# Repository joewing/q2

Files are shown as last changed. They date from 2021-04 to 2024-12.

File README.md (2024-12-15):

# Q2

A home-brew 12-bit mini-computer.

```
         __       __        
        /\ \     /\ \       000 | LDA | Z | A = [X]        
       /  \ \   /  \ \      001 | NOR | Z | A = A NOR [X] 
      / /\ \ \ / /\ \ \     010 | ADD | C | A = A + [X] 
     / / /\ \ \\/_/\ \ \    011 | SHR | C | A = [X] >> 1  
    / / /  \ \_\   / / /    100 | LEA | - | A = X 
   / / / __/ / /  / / /     101 | STA | - | [X] = A       
  / / / /\ \/ /  / / / __   110 | JMP | - | P = X
 / / /__\ \ \/  / / /_/\_\  111 | JFC | - | if !F: P = X  
/ / /____\ \ \ / /_____/ /   |
\/________\_\/ \________/   OOO D Z XXXXXXX - Operand
 joewing.net                     \ \_________ Zero Page
                                  \__________ Dereference
```

There are currently two hardware implementations of the Q2 instruction set:

  - [Q2](hardware/q2) - The bit-serial single-board discrete transistor implementation.
  - [Q2A](hardware/q2a) - A faster, parallel implementation using ATF16V8 PLDs.

Compared to the DEC PDP-8, the original Q2 would be like the PDP-8/S and
the Q2A would be like the PDP-8/I.

This repo contains the following subdirectories:
  - hardware - Hardware realizations.
    - [q2](hardware/q2) - The original discrete transistor Q2.
      - hdl - A Verilog model and test bench for simulating Q2 programs.
      - scad - An OpenSCAD 3d model for the case.
      - pcb - Schematics and PCB in KiCad
    - [q2a](hardware/q2a) - Programmable logic device implementation
      - pld - PLD files for programming the ATF16V8s and Verilog test bench
      - scad - An OpenSCAD 3d model for the case.
      - pcb - Schematics and PCB in KiCad
  - [q2asm](q2asm) - A Q2 assembler (in Rust).
  - [q2lc](q2lc) - A compiler for a simple language (in Rust).
  - [q2prog](q2prog) - A Q2 programmer (in Rust) for a Raspberry Pi
    (this is for the Q2 only; the Q2A requires an EEPROM programmer).
  - examples - Q2 example programs (assembly and Q2L).

See [joewing.net/projects/q2](https://joewing.net/projects/q2) for
more information.

## q2lc

q2lc is a compiler for Q2 programs. It is built using 'cargo build'
in the q2lc directory.

The Makefile will take care of compiling and assembling Q2L
programs in the examples directory automatically:

```
make examples/sieve.lst
```

This will compile sieve.q2l into sieve.q2 and then assemble
sieve.q2 using q2asm to generate sieve.lst along with sieve.q2p.

## q2asm

q2asm is the assembler for Q2 programs. It is built using 'cargo build'
in the q2asm directory.

The Makefile will take care of assembling programs in the examples
directory automatically:

```
make examples/hello.lst
```

This will generate the listing file for examples/hello.q2 as
examples/hello.lst.

## Instruction Set

All instructions are 1 word with the following format:

```
  FFF D Z XXXXXXX
   \  \ \    \____ Operand
    \  \ \________ Zero-Page    
     \  \_________ Dereference 
      \___________ Opcode
```

Instruction summary:

  Opcode  | Name  | F | Description
  ------- | ----- | - | ----------------
  000     | LDA   | Z | A = [X]
  001     | NOR   | Z | A = A NOR [X]
  010     | ADD   | C | A = A + [X]
  011     | SHR   | C | A = [X] >> 1
  100     | LEA   | - | A = X
  101     | STA   | - | [X] = A
  110     | JMP   | - | P = X
  111     | JFC   | - | if !F, P = X

The flag is set if carry ('C'), zero ('Z'), or left unchanged ('-').

The following address modes are supported:

  Value | DZ | Meaning
  ----- | --- | --------------------------------
  x     | 00 | current-page relative
  @x    | 10 | indirect through current page
  =x    | 01 | zero-page relative
  @=x   | 11 | indirect through zero page

For convenience, the assembler also supports two additional
address modes:

  Value | DZ | Meaning
  ----- | --- | --------------------------------
  #x    | 00 | immediate
  #@x   | 10 | immediate indirect

These cause an extra word to be allocated at the end of the
current page for an immediate value.

## Examples

```
; Negate: A = -A
  nor   #0
  add   #1
```

```
; Subtract: A - v
  nor   #0
  add   v       ; A = v - A - 1
  nor   #0      ; A = A - v
```

```
; Decrement A
  add   #-1
```

```
; NOT: A = ~A
  nor   #0
```

```
; OR: A = A | v
  nor   v
  nor   #0
```

```
; AND: A = A & v
  nor   #0
  sta   =t0   ; t0 = ~A
  lda   v
  nor   #0    ; A = ~v
  nor   =t0   ; A = ~(~A | ~v) = A & v
```

```
; Jump if F set
  jfc   $+2
  jmp   label
```

```
; Jump if a >= b
  lda   a
  nor   #0
  add   b
  jfc   ge
```

```
; Jump if a != b
  lda   a
  nor   #0
  add   b
  nor   #0
  jfc   ne
```

```
; Function call:
  lea   $+2   ; A = return address
  jmp   func

;...
func:
  sta   =ra   ; Save return address
  ; ...
  jmp   @=ra  ; Return

```

```
; Long jump
  jmp   @#addr
```

```
; Long call
  lea   $+2
  jmp   @#addr
```

```
; Rotate right function
; x0 >>> 1
ror:
  sta   =ra       ; save return address
  shr   =x0       ; A = x0 >> 1
  jfc   @=ra      ; return if no carry
  add   0x800
  jmp   @=ra
```

```
; Push A on to the stack
  sta   @=sp
  lda   =sp
  add   #-1
  sta   =sp
```

```
; Pop A off the stack
  lea   =1
  add   =sp
  sta   =sp
  lda   @=sp
```

## I/O

I/O is handled through address 0xFFF.

### LCD

Writes are directed to the LCD when the top 3 bits written to 0xFFF
are zero.  Writes to the LCD can be either commands or data.
The low 8-bits are sent directly to the LCD and the 9th bit determines
if data (0) or a command (1) is to be sent. Reads are not supported.

### Buttons

There are 5 buttons. Reading from 0xFFF returns the state of the
buttons in the low five bits where 0 is returned if the button is
pressed and 1 is returned if the button is not pressed.

### I2C

The SCL and SDA bits can be set by writing to 0xFFF with the top
bit set. Bit 9 controls SCL and bit 8 controls SDA.
Reads from 0xFFF return the state of the SCL and SDA bits.

### Memory Extension

The memory extension device allows the Q2 to address more than 4096
words of memory. This is accomplished through the use of two
additional latches: the data field (DF) and the instruction field (IF).
Memory accesses for indirect loads or stores have the data field
appended to the address. All other accesses have the instruction field
appended.

On reset, both the data and instruction fields are set to 0.
The data field can be set by writing 0xCxx to address 0xFFF (note that
the field is ignored for I/O). This will set the data field to xx.
The data field is copied to the instruction field when a jump takes
place.

### Summary

Writes:

  * 00 0 C DDDDDDDD - LCD
  * 10 C D 00000000 - I2C (C for SCL, D for SDA)
  * 11 0 0 0000000F - Field

Reads:

  * 11 C D 111KKKKK

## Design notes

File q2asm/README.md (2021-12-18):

# Q2 Assembler

q2asm is an assembler for Q2 programs.

See [joewing.net/projects/q2/asm](https://joewing.net/projects/q2/asm)
for more information.

## Building

* q2asm is written in Rust, so the first step is to
  [install Rust](https://www.rust-lang.org/tools/install)
  (note that rustup will also install cargo, which is required).
* Once rust and cargo are installed, run `cargo build`
  from this directory.
* q2asm will be available as `target/debug/q2asm`, which can
  be used from this location or copied to a location in your path.

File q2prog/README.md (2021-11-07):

# Q2 Programmer

q2prog is a Q2 programmer for the Raspberry Pi.

## Building

* q2prog is written in Rust, so the first step is to
  [install Rust](https://www.rust-lang.org/tools/install)
  (note that rustup will also install cargo, which is required).
* Once rust and cargo are installed, run `cargo build`
  from this directory.
* The q2prog will be available as `target/debug/q2prog`, which can
  be used from this location or copied to a location in your path.

## Usage

To program the Q2, connect a 40-pin connector to both the GPIO pins
of the Raspberry Pi and the Q2 (be sure the pins line up correctly).
Make sure all input switches on the Q2 are "off". Some of the data LEDs
will glow, but that is just due to pull-downs on some of the GPIO pins.

To write an assembled program (prog.q2p), on the Raspberry Pi run:

```
  q2prog write -f prog.q2p
```

For more options, see `q2prog -h`.

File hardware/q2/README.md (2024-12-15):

# Q2

Hardware for the Q2 12-bit bit-serial single-board discrete
transistor computer.

This is what it looks like:

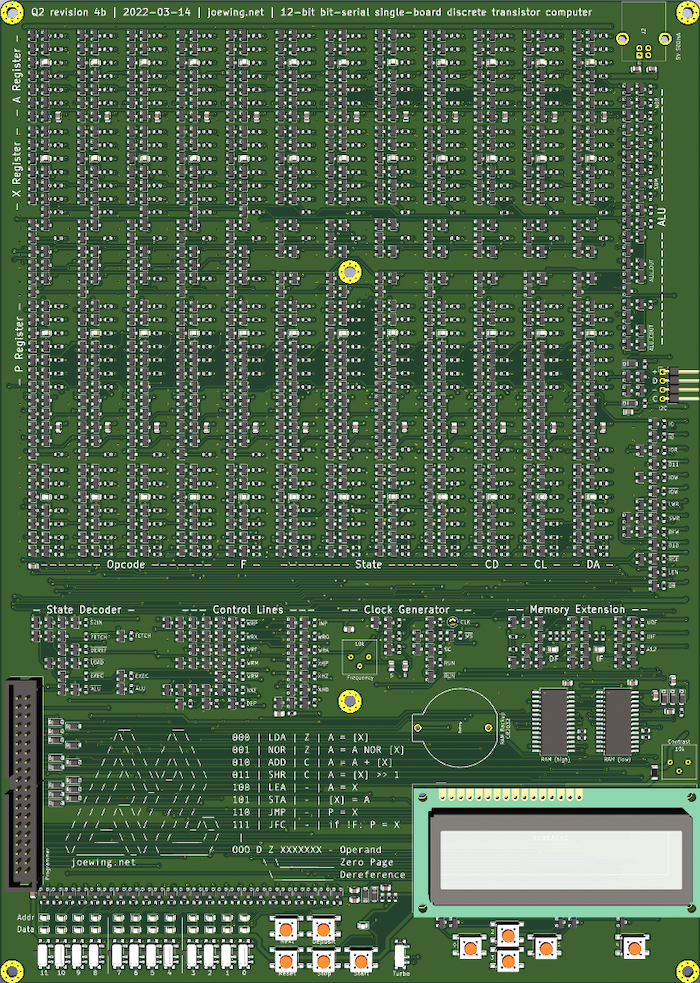
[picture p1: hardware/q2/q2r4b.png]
Q4 revision 4b


## PCB Fabrication and Assembly

The Q2 is a dual-layer PCB about the size of a sheet of paper allowing
it to be fabricated just about anywhere.
For assembly, the BOM is stored with the schematic to reference the
necessary surface-mount components. Due to the large number of components,
I use a turn-key assembly service. Although numerous, all of the components
are fairly standard making them cheap and widely available.

The large number of components makes the price for assembly
vary quite a bit from company to company. It's probably no surprise,
but the cheapest I've found is JLCPCB. I've been
satisfied with all the boards from them so far.

Unfortunately, JLCPCB's online Gerber viewer is incapable of showing a
board of this complexity.
To work around this without taking too big a leap of faith, I typically
upload several test boards to make sure I have component orientations
and positions correct.
Component orientation can be mostly fixed using
[JLCKicadTools](https://github.com/matthewlai/JLCKicadTools).
However, I typically run into a few components that need to be
fixed up when trying out new switches, etc.

Another issue with JLCPCB is that having more than 1000 of the same
component appears to cause problems such that they reject the BOM.
When necessary, I work around this by arbitrarily assigning different
values to the components to cause them to spill into multiple rows
in the BOM.

## Requirements

### For software development:

 * Rust - q2lc, q2asm, and q2prog are written in
  [Rust](https://www.rust-lang.org/tools/install).

### For programming:

 * Raspberry Pi - The GPIO pins on a
  [Raspberry Pi](https://www.raspberrypi.org) are used to
  program the Q2. The exact model does not matter, though older
  Pis with only 26 GPIO pins will not be able to read programs
  back from the Q2. A Raspberry Pi can be used as a complete
  development environment for the Q2.

### For simulation:

 * iverilog - [Icarus Verilog](http://iverilog.icarus.com) can be
  used to run the Verilog model.

### To make the hardware:

 * KiCad - The PCB and schematics are in
  [KiCad](https://kicad.org) 6. Note: the design was originally
  in KiCad 5 and the SOT-23 footprint became much larger with version 6.
  Therefore, to get the board to appear correctly it is necessary to use
  the footprint from KiCad 5. Unfortunately there doesn't seem to be
  a new footprint that works. See
  [Gitlab issue 2523](https://gitlab.com/kicad/libraries/kicad-footprints/-/issues/2523).
 * OpenSCAD - The 3D model for the case is written in
  [OpenSCAD](http://www.openscad.org).

## Programming

q2prog is run on a Raspberry Pi to program the Q2.
It is built using 'cargo build' in the q2prog directory.

To program the Q2, connect a 40-pin connector to both the GPIO pins
of the Raspberry Pi and the Q2 (be sure the pins line up correctly).
Make sure all input switches on the Q2 are "off". Some of the data LEDs
will glow, but that is just due to pull-downs on some of the GPIO pins.

To write a program (examples/hello.q2p) to the Q2:

```
make prog-hello
```

This will also build examples/hello.q2p if necessary.

To verify that the program was correctly written:

```
make verify-hello
```

Note that if q2prog is killed, the Raspberry Pi will hold the switches
in some state that is likely not zero. This means you will either
need to disconnect the Raspberry Pi or run q2prog to completion before
using the Q2.

## Simulation

Simulation of Q2 programs can be performed using the Verilog model.
The model reads in "test.hex" and runs the simulation outputting
a simulated 16x2 LCD (characters only) every time it is updated.

For convenience, the Makefile will take care of setting everything up.
Simply place the program to be simulated in the examples directory
and run 'make sim-name'. This will assemble and simulate
'examples/name.q2' (first compiling 'examples/name.q2l' if required).

## Power Consumption

The primary source of power consumption in the Q2 comes from pull-up
networks. For simplicity, most of the pull-ups are simply resistors,
though some of them have an LED in series to show the state.
We can easily compute the worst-case power draw by assuming all
pull-up networks are grounded.
The power consumption varies depending on the value of the resistor
and the presence of the LED:

  * 75 LEDs (2V drop) with 1k resistors: 75 * (5 - 2) / 1000 = 225mA
  * 6    1k resistors:  30.0mA
  * 10 4.7k resistors:  10.6mA
  * 48 6.8k resistors:  35.3mA
  * 244 10k resistors: 122.0mA
  * 48  22k resistors:  10.9mA
  * 31 100k resistors:   1.5mA

In addition to the pull-up network, the Q2 has the following components
that draw power:

  * The SRAMs each use 10mA (20mA total).
  * The LCD is assumed to use around 20mA.

This gives us a total power consumption of about 475mA.

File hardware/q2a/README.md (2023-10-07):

# Q2A

Hardware for the Q2 12-bit computer made from programmable logic devices.
Compared to the original Q2, the Q2A should be easier to have fabricated
(it uses through-hole components making it easy to hand assemble). In
addition, the Q2A has a faster clock and a nicer enclosure.

Note that the current iteration of the Q2A does not support the memory
extension device or I2C.

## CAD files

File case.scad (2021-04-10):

board_width = 150;
board_depth = 180;
base_height = 10;
panel_width = board_width;
panel_height = 100;
panel_depth = 10;
tol = 2;
thickness = 1.6 + tol;
switch_radius = 3.1;
switch_spacing = 3.5;
screw_radius = 1.7;
screw_head_radius = 2.8;
screw_head_height = 3;
standoff_height = base_height - 1.6;
standoff_radius = screw_head_radius * 1.5;


// center to center of the standoffs should be 143mm.
screw_offset = 3.5;
standoff_positions = [
    [screw_offset, screw_offset],
    [board_width - screw_offset, screw_offset],
    [screw_offset, board_depth - screw_offset],
    [board_width - screw_offset, board_depth - screw_offset]
];

module meniscus(height, radius) {
    difference() {
        cube([radius, radius, height]);
        cylinder(height, radius + 0.2, radius + 0.2);
    }
}

module rounded_cube(x, y, z, r = 3) {
    difference() {
        cube([x, y, z]);
        translate([x - r, y - r]) meniscus(z, r);
        translate([r, y - r]) rotate([0, 0, 90]) meniscus(z, r);
        translate([r, r]) rotate([0, 0, 180]) meniscus(z, r);
        translate([x - r, r]) rotate([0, 0, 270]) meniscus(z, r);
    }
}

module switches(x, y, count, notch) {
    for (i = [0:count-1]) {
        bump = x + i > 4 ? (x + i > 8 ? 9 : 5) : 1;
        translate([
            bump + (x + i) * switch_radius * switch_spacing + tol + 0.5,
            y * switch_radius * switch_spacing + tol,
            panel_depth - thickness
        ]) {
            cylinder(thickness, switch_radius, switch_radius, $fn=32);
        }
    }
}

module label(x, y, text) {
    size = 3;
    bump = x > 4 ? (x > 8 ? 9 : 5) : 1;
    translate([
        bump + x * switch_radius * switch_spacing - switch_radius + tol,
        y * switch_radius * switch_spacing - switch_radius * 2.5 + tol,
        panel_depth - thickness / 2
    ]) {
        linear_extrude(thickness / 2) {
            text(text = text, font = "Copperplate:style=bold", size = size, spacing=1.1);
        }
    }
}

module standoff(x, y) {
    translate([x + thickness, y + thickness, thickness]) {
        cylinder(standoff_height, standoff_radius, standoff_radius, $fn=16);
    }
}

module standoff_hole(x, y) {
    translate([x + thickness, y + thickness, 0]) {
        cylinder(standoff_height + thickness + tol, screw_radius, screw_radius, $fn=16);
        cylinder(screw_head_height, screw_head_radius, screw_head_radius, $fn=16);
    }
}

module render_base() {
    difference() {
        rounded_cube(
            board_width + 2 * thickness,
            board_depth + 2 * thickness,
            base_height + thickness
        );
        translate([thickness - tol, thickness - tol, thickness]) {
            rounded_cube(board_width + tol * 2, board_depth + tol * 2, base_height);
        }
    }
    for (pos = standoff_positions) {
        standoff(pos[0], pos[1]);
    }
}

module render_panel() {
    difference() {
        rounded_cube(panel_width + 2 * thickness, panel_height + 2 * thickness, panel_depth);
        translate([thickness - tol, thickness - tol, -thickness]) {
            rounded_cube(panel_width + tol * 2, panel_height + tol * 2, panel_depth);
        }
        
        // Data LEDs
        switches(1, 8, 12, false);
        label(1, 8, "Address");
        
        // Address LEDs
        switches(1, 6, 12, false);
        label(1, 6, "Data");
        
        // Power switch and LED.
        switches(1, 4, 1, true);
        switches(2, 4, 1, false);
        label(1, 4, "Power");
        
        // Speed
        switches(4, 4, 1, false);
        label(4, 4, " 5k");
        
        // Run LED, start, stop
        switches(6, 4, 1, false);
        switches(7, 4, 2, true);
        label(7, 4, "RUN");
        label(8, 4, "HLT");
        
        // Rest, increment, deposit
        switches(10, 4, 3, true);
        label(10, 4, "SET");
        label(11, 4, "INC");
        label(12, 4, "DEP");
        
        // Input switches
        switches(1, 2, 12, true);
        label(1, 2, "Input");
    }
}

difference() {
    union() {
        render_base();
        translate([0, base_height / 2 - tol, 0]) {
            rotate([60, 0, 0]) {
                render_panel();
            }
        }
    }
    for (pos = standoff_positions) {
        standoff_hole(pos[0], pos[1]);
    }
}

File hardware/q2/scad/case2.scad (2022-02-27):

board_width = 198;
board_height = 278;
wall_width = 2;
board_overlap = 2.5;
tol = 0.2;
screw_radius = 1.7;
screw_head_radius = 2.8;
screw_head_height = 3;
screw_offset = 3.5;
standoff_height = 8;
standoff_radius = screw_head_radius * 1.25;

case_width = board_width + (wall_width + tol) * 2;
case_height = board_height + (wall_width + tol) * 2;
case_depth = 1.6 + standoff_height + wall_width + tol;
midpoint = 140;

standoff_positions = [
    [screw_offset, screw_offset],
    [board_width - screw_offset, screw_offset],
    [board_width / 2, 79.9],
    [board_width / 2, 201.2],
    [screw_offset, board_height - screw_offset],
    [board_width - screw_offset, board_height - screw_offset],
];

module meniscus(height, radius) {
    difference() {
        cube([radius + 0.1, radius + 0.1, height]);
        translate([-0.1, -0.1, -0.1]) {
            cylinder(height + 0.1, radius + 0.1, radius + 0.1, $fn=32);
        }
    }
}

module rounded_cube(x, y, z, r = 3) {
    difference() {
        cube([x, y, z]);
        translate([x - r, y - r]) meniscus(z, r);
        translate([r, y - r]) rotate([0, 0, 90]) meniscus(z, r);
        translate([r, r]) rotate([0, 0, 180]) meniscus(z, r);
        translate([x - r, r]) rotate([0, 0, 270]) meniscus(z, r);
    }
}

module screw_hole(x, y) {
    translate([x + wall_width, y + wall_width, -tol]) {
        cylinder(
            standoff_height + wall_width + tol * 2,
            screw_radius,
            screw_radius,
            $fn=32
        );
        cylinder(
            screw_head_height + tol * 2,
            screw_head_radius,
            screw_head_radius,
            $fn=32
        );
    }
}

module clip() {
    base_radius = 4;
    board_width = 1.6;
    hole_radius = 1.4;
    difference() {
        union() {
            cylinder(d=hole_radius * 2, h=board_width, $fn=64);
            translate([0, 0, board_width]) {
                intersection() {
                    union() {
                        translate([0, 0, 0.5]) {
                            cylinder(d1 = hole_radius * 2.5, d2 = hole_radius * 1.5, h = 2, $fn=64);
                        }
                        cylinder(d1 = hole_radius * 2, d2 = hole_radius * 2.5, h = 0.5, $fn=64);
                    }
                    cube([hole_radius * 2, base_radius * 2, base_radius * 2], center=true);
                }
            }
        }
        translate([0, 0, (board_width + 20) / 2])cube([20, 0.4, 20], center=true);
    }
}

module standoff(x, y) {
    translate([x + wall_width, y + wall_width, wall_width]) {
        cylinder(standoff_height, standoff_radius, standoff_radius, $fn=32);
    }
    translate([x + wall_width, y + wall_width, wall_width + standoff_height]) {
        clip();
    }
}


module full_case() {
    union() {
        difference() {
            rounded_cube(case_width, case_height, case_depth);
            translate([wall_width + board_overlap, wall_width + board_overlap, wall_width]) {
                rounded_cube(
                    case_width - board_overlap * 2 - wall_width * 2,
                    case_height - board_overlap * 2 - wall_width * 2 + tol,
                    standoff_height
                );
            }
            translate([
                wall_width - tol,
                wall_width - tol,
                standoff_height + wall_width
            ]) {
                rounded_cube(
                    board_width + tol,
                    board_height + tol,
                    case_depth - standoff_height
                );
            }
        }
        for (pos = standoff_positions) {
            standoff(pos[0], pos[1]);
        }
    }
}


module interlock() {
    translate([0, midpoint, case_depth / 2]) {
        rotate([0, 90, 0]) {
            rotate([0, 0, -30]) {
                cylinder(case_width, case_depth, case_depth, $fn=3);
            }
        }
    }
}

module front_half() {
    translate([0, -0, 0]) {
        intersection() {
            full_case();
            union() {
                cube([case_width, midpoint, case_depth * 2]);
                interlock();
            }
        }
    }
}

module back_half() {
    translate([0, 0, 0]) {
        intersection() {
            full_case();
            difference() {
                translate([0, midpoint, 0]) {
                    cube([case_width, case_height - midpoint, case_depth * 2]);
                }
                interlock();
            }
        }
    }
}

//front_half();
back_half();

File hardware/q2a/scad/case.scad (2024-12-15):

board_width = 196;
board_depth = 160;
base_height = 11.6;
panel_width = board_width;
panel_height = 100;
panel_depth = 10;
panel_angle = 60;
pcb_thickness = 1.6;
tol = 2;
thickness = 3.6;
switch_radius = 3.6;
led_radius = 1.7;
switch_spacing = 3.5;
screw_radius = 1.9;
screw_head_radius = 2.9;
screw_head_height = 3.1;
standoff_height = thickness + base_height - screw_head_height - pcb_thickness;
standoff_radius = 3.6;
board_offset = 40;
switch_offset = 10;
extra = 1.0;    // Extra cutout for PCB


standoff_positions = [
    [standoff_radius, standoff_radius],
    [board_width - standoff_radius, standoff_radius],
    [standoff_radius, board_depth - standoff_radius],
    [board_width - standoff_radius, board_depth - standoff_radius],
];

module meniscus(height, radius) {
    difference() {
        translate([0,0, -1]) cube([radius, radius, height + 2]);
        cylinder(height + 0.01, radius + 0.2, radius + 0.2);
    }
}

module rounded_cube(x, y, z, r = 3) {
    difference() {
        cube([x, y, z]);
        translate([x - r, y - r]) meniscus(z + 0.01, r + 0.01);
        translate([r, y - r]) rotate([0, 0, 90]) meniscus(z + 0.01, r + 0.01);
        translate([r, r]) rotate([0, 0, 180]) meniscus(z + 0.01, r + 0.01);
        translate([x - r, r]) rotate([0, 0, 270]) meniscus(z + 0.01, r + 0.01);
    }
}

// 1 on each side, and 1/2 for nibble spacing:
switch_spacingx = panel_width / (3 * 0.5 + 2 * 0.5 + 15);

// 4 lines with extra on the top and bottom divides the panel into 5:
switch_spacingy = panel_height / (1 + 4);

function bumps(x) = x > 3 ? (x > 7 ? (x > 11 ? 2 : 1.5) : 1.0) : 0.5;

module switches(x, y, count, is_switch = true) {
    radius = is_switch ? switch_radius : led_radius;
    for (i = [0:count-1]) {
        bump = bumps(x + i);
        translate([
            thickness + (x + i + bump - 0.5) * switch_spacingx,
            (y) * switch_spacingy + base_height + thickness,
            panel_depth - thickness - tol
        ]) {
            cylinder(panel_depth, radius, radius, $fn=32);
        }
    }
}

module label(x, y, text, size = 3.2) {
    bump = bumps(x);
    translate([
        (x + bump - 0.5) * switch_spacingx,
        (y) * switch_spacingy - 2.5 * switch_radius + base_height + thickness,
        panel_depth + thickness / 2 + 0.01
    ]) {
        linear_extrude(thickness / 2) {
            text(text = text, font = "Copperplate:style=bold", size = size, spacing=1.1);
        }
    }
}

module standoff(x, y) {
    translate([x, y, thickness - 0.01]) {
        cylinder(standoff_height, standoff_radius, standoff_radius, $fn=32);
    }
}

module standoff_hole(x, y, flip = false) {
    translate([x, y, -tol - thickness]) {
        cylinder(standoff_height + tol + thickness + pcb_thickness, screw_radius, screw_radius, $fn=32);
        translate([0, 0, flip ? standoff_height + thickness + tol - screw_head_height : 0]) {
            cylinder(screw_head_height + tol, screw_head_radius, screw_head_radius, $fn=32);
        }
    }
}

module render_base() {
    difference() {
        rounded_cube(
            board_width + 2 * thickness,
            board_depth + 2 * thickness + board_offset,
            base_height + thickness
        );
        translate([thickness - extra, thickness - extra, thickness + 0.01]) {
            rounded_cube(board_width + extra * 2, board_depth + board_offset + extra * 2, base_height);
        }
    }
    translate([thickness, thickness + board_offset, 0]) {
        for (pos = standoff_positions) {
            standoff(pos[0], pos[1]);
        }
    }
}

module render_panel() {
    difference() {
        union() {
            difference() {
                rounded_cube(panel_width + 2 * thickness, panel_height + 2 * thickness + base_height, panel_depth + thickness);
                translate([thickness - extra, thickness + base_height - extra, -thickness]) {
                    rounded_cube(panel_width + 2 * extra, panel_height + 2 * extra, panel_depth + thickness);
                }
            }
            translate([0, base_height, 0]) {
                cube([thickness + standoff_radius, panel_height + thickness + extra, panel_depth + thickness]);
            }
            translate([panel_width - standoff_radius + thickness, base_height, 0]) {
                cube([thickness + standoff_radius, panel_height + thickness + extra, panel_depth + thickness]);
            }
            translate([thickness, base_height + panel_height + thickness + 2 * extra, 0]) {
                difference() {
                    rotate([60, 0, 0]) {
                        cube([panel_width, panel_depth * 2, panel_depth * 2]);
                    }
                    translate([-1, -panel_depth * 2, panel_depth + thickness - extra]) {
                        cube([panel_width + 2, panel_depth * 4, panel_depth * 4]);
                    }
                    translate([-1, -extra, -panel_depth * 2]) {
                        cube([panel_width + 2, panel_depth * 2, panel_depth * 4]);
                    }
                }
            }
            translate([thickness, thickness, -thickness]) {
                standoff(standoff_radius, base_height + standoff_radius);
                standoff(panel_width - standoff_radius, base_height + standoff_radius);
                standoff(standoff_radius, base_height + panel_height - standoff_radius);
                standoff(panel_width - standoff_radius, base_height + panel_height - standoff_radius);
            }
        }
        
        translate([thickness, thickness, thickness]) {
            standoff_hole(standoff_radius, base_height + standoff_radius, true);
            standoff_hole(panel_width - standoff_radius, base_height + standoff_radius, true);
            standoff_hole(standoff_radius, base_height + panel_height - standoff_radius, true);
            standoff_hole(panel_width - standoff_radius, base_height + panel_height - standoff_radius, true);
        }
        
        // Field LEDs
        switches(1, 4, 3, false);
        label(1, 4, "Field");
        
        // Address LEDs
        switches(4, 4, 12, false);
        label(4, 4, "Address");
        
        // Data LEDs
        switches(4, 3, 12, false);
        label(4, 3, "Data");
        
        // Power switch and LED
        switches(1, 2, 1, false);
        switches(2, 2, 1, true);
        label(1, 2, "Power");

        // Run LED, start, stop
        switches(4, 2, 1, false);
        switches(5, 2, 2, true);
        label(4, 2, "RUN");
        label(6, 2, "HLT");
        
        // Reset / Increment / Deposit
        switches(11, 2, 1, true);
        switches(13, 2, 2, true);
        label(11, 2, "SET");
        label(13, 2, "INC");
        label(14, 2, "DEP");
        
        // Field switches
        switches(1, 1, 3, true);
        label(1, 1, "Field");
        
        // Data switches
        switches(4, 1, 12, true);
        label(4, 1, "Input");
        
        label(11, 0.25, "Q2A", 12);
    }
}

difference() {
    union() {
        render_base();
        translate([0, board_offset / 2, base_height]) {
            height = (panel_height + thickness + base_height / 2) * sin(panel_angle);
            width = (panel_height + thickness + base_height / 2) * cos(panel_angle) - 2;
            translate([0, -board_offset / 4, 0]) difference() {
                cube([board_width + thickness * 2, width, height]);
                translate([-1, -1, 0]) rotate([panel_angle, 0, 0]) {
                    cube([board_width + thickness * 2 + 2, board_depth, height]);
                }
                translate([thickness - extra, 0, -1]) {
                    cube([board_width + extra * 2, board_depth + extra + board_offset, height + 2]);
                }
            }
        }
        translate([0, base_height / 2 - 0.2, 2]) {
            rotate([panel_angle, 0, 0]) {
                render_panel();
            }
        }
    }
    translate([thickness, thickness + board_offset, thickness]) {
        for (pos = standoff_positions) {
            standoff_hole(pos[0], pos[1]);
        }
    }
}

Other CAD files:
hardware/q2a/scad/led-stand.scad

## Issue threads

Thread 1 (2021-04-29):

Support for some unix-like environment?

dumblob, 2021-04-29:
First of all, this looks awesome! It's great to someone nowadays to play with such stuff! It reminds me of https://monster6502.com/ .

A year ago I saw https://collapseos.org/ . Few weeks ago I saw https://github.com/EtchedPixels/FUZIX . Today I see *q2*.

Have you thought of some unix-like interactive environment for *q2* or something like the Collapse OS?

----

Btw. what were your thoughts of constructing own memory from "discrete" parts? I'm asking because that was the first thing I was looking for when I saw the description "12-bit single-board discrete transistor computer" :wink:.

joewing, 2021-04-30:
Yeah, the MOnSter 6502 is a cool project.
It would be neat to have a high-level language and small OS environment, but for now I'm more focused on the actual hardware aspects. I think having external storage in the form of EEPROM would be necessary to make something like an OS useful (which is why I'm looking into an I2C interface now).

As far as RAM is concerned, it's tricky because it would use so many transistors. Even just the address decoder would be a lot of transistors. Of course, creating the PCB would be fairly easy (just replicate the same thing 2048 times or whatever), but it would be huge (and/or many), expensive, and power-hungry. This is why old computers used core memory, Williams tubes, delay lines, etc. Also, having the RAM be non-volatile is a must I think, so that also limits power consumption or forces the use of something like core memory.

dumblob, 2021-04-30:
>which is why I'm looking into an I2C interface now

I2C sounds pretty complex for such a simple device - but probably worth it considering you want to connect modern chips to it :wink:.

Regarding RAM - I was first thinking of delay lines, but that wouldn't scale. Second thought was core memory which I thought would be possible to completely redesign for PCB manufacturing. And that's what I was first looking for in your schemes :wink:. And thanks for the pointer to Willliams tubes - they seem extremely power hungry and sensitive to the environment, but it's an interesting piece of technology. Not sure though whether the decoder could be slimmed down - will think about it a bit ;)

dumblob, 2021-11-20:
Btw. regarding delay line RAM there are some interesting attempts to make it work as a DIY product:

http://www.decodesystems.com/delay-line-memory.html
http://jhallenworld.blogspot.com/2014/01/acoustic-delay-line-memory.html
https://www.youtube.com/watch?v=tQyX3F4ggM8

To me it still looks a bit easier than to immitate core memory with SMD parts on a PCB (if even possible).

Also the only thing I know of which is "fast" (in terms of "useful for a CPU from discrete components") and non-volatile is bubble memory. But its consumption is also non-negligible (because its operating temperature is around 45 Celsius if I'm not mistaken which means also tens of seconds delay when "booting"). It's though IMHO rather impossible to construct bubble memory from discrete components as many parts of it aren't manufactured for any existing product. Twister memory (predecessor to bubble memory) could work, but it's essentially a smaller variant of core memory which again means it's rather impossible to manufacture.

Maybe we could think of some capacitor memory - two PCBs (with very fine cell-like etched structures) on top of each other with some thin insulator in between and refreshing oscillator. IDK, just crazy brainstorming ...

dumblob, 2022-05-04:
After discovering http://www.northdownfarm.co.uk/rory/tim/tim-8.htm I think [capacitor memory](https://hackaday.io/page/2506-diode-capacitor-ram ) (in an SMD miniaturized form perhaps on doublesided PCBs) is a viable option even for many kilobytes of memory.

Thoughts?

joewing, 2022-05-08:
I've put some thought into using a DRAM like structure using two NMOS transistors and a capacitor per bit. The implementation is pretty straightforward and it uses about as few components as I think one can get away with. The diode version might be somewhat cheaper to implement, though I haven't done much experimentation with it.

For a DRAM of say, 1024 words, which is probably about the minimum number that would be useful I think, it would take 2*12*1024 = 24576 transistors and 12288 capacitors just for the storage. Assuming we could somehow share the sense amplifiers, the extra transistors for that would be negligible (probably nor more than 10 or so transistors?). I would guess this would have to be divided among multiple (hopefully identical) PCBs, and each would end up with its own sense amplifier. Implementing an address decoder would take lg(1024) = 10 transistors per word or 10240 transistors assuming the obvious implementation, though that could be reduced to slightly more than 5120 by re-using the outputs of some transistors. So the whole thing would come to something like 30k transistors. Getting that many transistors on a single PCB probably isn't realistic, but 2k would probably be doable. So that comes to 16 PCBs each with around 2k transistors to handle 64 words (768 bits).

Of course, the more complicated part would be adding extra states to handle pre-charge for each memory access and a periodic refresh. For the refresh, each DRAM board could potentially be refreshed in parallel during ALU operations (assuming each board had its own sense amplifiers). This would require the addition of a 6-bit counter. Then again, if we add a sense amplifier for each 8 words, we could get away with just using the ALU state machine to drive the refresh.

In any case, it's a neat idea.. though I don't particularly like the idea of making the ram volatile.

dumblob, 2022-05-09:
>In any case, it's a neat idea.. though I don't particularly like the idea of making the ram volatile.

It is definitely risky. But really neat as you say. If I found some time in the coming years (yeah, family life is very unpredictable :wink:), I will think about building such memory with refresh.

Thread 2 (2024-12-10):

[Suggestion] Release with gerber files

bastetfurry, 2024-12-10:
Due to the complexity of the project it would be cool if, for people who just want the hardware to play around with, you could add ready to use gerber and BOM files one can upload to, for example, JLC.
Especially with the little "bug/feature" of KiCAD 6 with the larger mosfet part.

joewing, 2024-12-14:
I just attached the gerber files and BOM used to create the 4c version of the board to the release: https://github.com/joewing/q2/releases/tag/rev4b

That should include everything necessary to have the board produced and assembled by JLCPCB. It's been a while, but I think that board works pretty much as is as long as you don't push the clock frequency too much.
I've made some more recent changes, but I haven't actually pulled the trigger on producing the board yet.

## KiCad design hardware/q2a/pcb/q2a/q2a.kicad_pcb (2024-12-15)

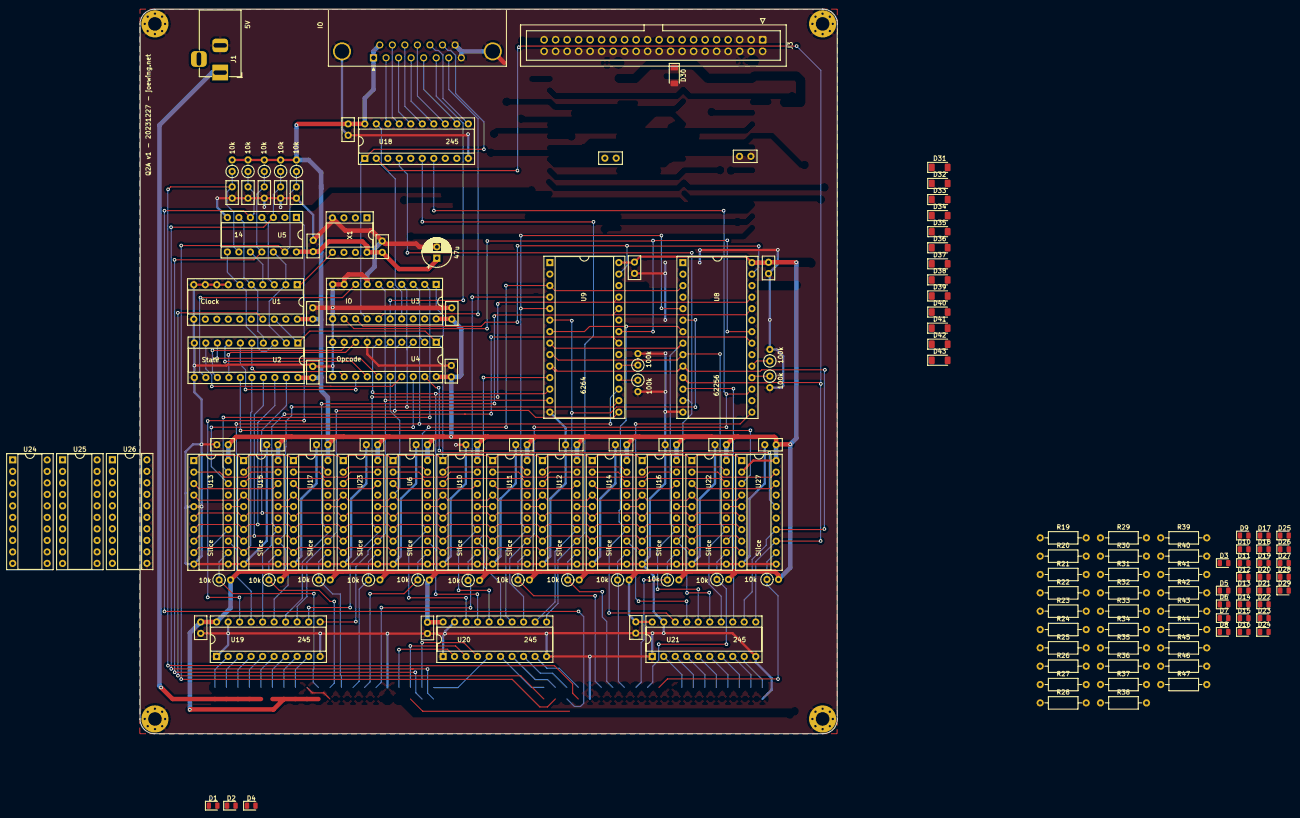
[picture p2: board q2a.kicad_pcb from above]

Board: 2 copper layers, 154.0 x 160.0 mm, 159 parts (0 on the bottom side), 191 nets.

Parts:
C1, C2, C3, C4, C5, C6, C7, C8, C10, C11, C12, C13, C14, C15, C16, C17, C18, C19, C20, C21, C22, C23, C24, C25, C26, C27, C28, C29, C30, C31, C32: 0.1u; C_Disc_D5.0mm_W2.5mm_P2.50mm
C9: 47u; CP_Radial_D6.3mm_P2.50mm
D1, D2, D3, D4, D5, D6, D7, D8, D9, D10, D11, D12, D13, D14, D15, D16, D17, D18, D19, D20, D21, D22, D23, D24, D25, D26, D27, D28, D29: LED; LED_0805_2012Metric
D30, D31, D32, D33, D34, D35, D36, D37, D38, D39, D40, D41, D42, D43: 1N4148; D_MiniMELF
H1, H2, H3, H4: MountingHole_Pad; MountingHole_3mm_Pad_Via
J1: Barrel_Jack_MountingPin; BarrelJack_Horizontal
J2: IO; DSUB-15_Female_Horizontal_P2.77x2.84mm_EdgePinOffset7.70mm_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
J3: Programmer; IDC-Header_2x20_P2.54mm_Vertical
R1, R2, R3, R4, R5, R6, R11, R12, R13, R14, R15, R16, R17, R18, R48, R49, R50: 10k; R_Axial_DIN0207_L6.3mm_D2.5mm_P2.54mm_Vertical
R7, R8, R9, R10: 100k; R_Axial_DIN0207_L6.3mm_D2.5mm_P2.54mm_Vertical
R19, R20, R21, R22, R23, R24, R25, R26, R27, R28, R29, R30, R31, R32, R33, R34, R35, R36, R37, R38, R39, R40, R41, R42, R43, R44, R45, R46, R47: 10k; R_Axial_DIN0207_L6.3mm_D2.5mm_P10.16mm_Horizontal
U1: Clock; DIP-20_W7.62mm_Socket
U2: State; DIP-20_W7.62mm_Socket
U3: IO; DIP-20_W7.62mm_Socket
U4: Opcode; DIP-20_W7.62mm_Socket
U5: 14; DIP-14_W7.62mm_Socket
U6, U10, U11, U12, U13, U14, U15, U16, U17, U22, U23, U27: Slice; DIP-20_W7.62mm_Socket
U8: 62256; DIP-28_W15.24mm_Socket
U9: 6264; DIP-28_W15.24mm_Socket
U18, U19, U20, U21: 245; DIP-20_W7.62mm_Socket
U24: Field 2; DIP-20_W7.62mm_Socket
U25: Field 1; DIP-20_W7.62mm_Socket
U26: Field 0; DIP-20_W7.62mm_Socket
X1: CXO; DIP-8_W7.62mm_Socket

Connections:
/Bit 0/COUT: U22.3 (I3), U27.18 (IO2)
/Bit 0/IOOUT: U22.2 (I2), U27.19 (IO1)
/Bit 0/NEXTX: U22.16 (IO4), U27.5 (I5)
/Bit 1/COUT: U16.3 (I3), U22.18 (IO2)
/Bit 1/IOOUT: U16.2 (I2), U22.19 (IO1)
/Bit 1/NEXTX: U16.16 (IO4), U22.5 (I5)
/Bit 2/COUT: U14.3 (I3), U16.18 (IO2)
/Bit 2/IOOUT: U14.2 (I2), U16.19 (IO1)
/Bit 2/NEXTX: U14.16 (IO4), U16.5 (I5)
/Bit 3/COUT: U12.3 (I3), U14.18 (IO2)
/Bit 3/IOOUT: U12.2 (I2), U14.19 (IO1)
/Bit 3/NEXTX: U12.16 (IO4), U14.5 (I5)
/Bit 4/COUT: U11.3 (I3), U12.18 (IO2)
/Bit 4/IOOUT: U11.2 (I2), U12.19 (IO1)
/Bit 4/NEXTX: U11.16 (IO4), U12.5 (I5)
/Bit 5/COUT: U10.3 (I3), U11.18 (IO2)
/Bit 5/IOOUT: U10.2 (I2), U11.19 (IO1)
/Bit 5/NEXTX: U10.16 (IO4), U11.5 (I5)
/Bit 6/COUT: U6.3 (I3), U10.18 (IO2)
/Bit 6/IOOUT: U6.2 (I2), U10.19 (IO1)
/Bit 6/NEXTX: U6.16 (IO4), U10.5 (I5)
/Bit 7/COUT: U6.18 (IO2), U23.3 (I3)
/Bit 7/IOOUT: U6.19 (IO1), U23.2 (I2)
/Bit 7/NEXTX: U6.5 (I5), U23.16 (IO4)
/Bit 8/COUT: U17.3 (I3), U23.18 (IO2)
/Bit 8/IOOUT: U17.2 (I2), U23.19 (IO1)
/Bit 8/NEXTX: U17.16 (IO4), U23.5 (I5)
/Bit 10/CIN: U15.3 (I3), U17.18 (IO2)
/Bit 10/COUT: U13.3 (I3), U15.18 (IO2)
/Bit 10/IOIN: U15.2 (I2), U17.19 (IO1)
/Bit 10/IOOUT: U13.2 (I2), U15.19 (IO1)
/Bit 10/NEXTX: U13.16 (IO4), U15.5 (I5)
/Bit 10/X: U15.16 (IO4), U17.5 (I5)
ABUS0: U8.10 (A0), U9.10 (A0), U21.12 (B6), U27.14 (IO6)
ABUS1: U8.9 (A1), U9.9 (A1), U21.14 (B4), U22.14 (IO6)
ABUS2: U8.8 (A2), U9.8 (A2), U16.14 (IO6), U21.16 (B2)
ABUS3: U8.7 (A3), U9.7 (A3), U14.14 (IO6), U21.18 (B0)
ABUS4: U8.6 (A4), U9.6 (A4), U12.14 (IO6), U20.12 (B6)
ABUS5: U8.5 (A5), U9.5 (A5), U11.14 (IO6), U20.14 (B4)
ABUS6: U8.4 (A6), U9.4 (A6), U10.14 (IO6), U20.16 (B2)
ABUS7: U6.14 (IO6), U8.3 (A7), U9.3 (A7), U20.18 (B0)
ABUS8: U8.25 (A8), U9.25 (A8), U19.12 (B6), U23.14 (IO6)
ABUS9: U8.24 (A9), U9.24 (A9), U17.14 (IO6), U19.14 (B4)
ABUS10: U8.21 (A10), U9.21 (A10), U15.14 (IO6), U19.16 (B2)
ABUS11: U8.23 (A11), U9.23 (A11), U13.14 (IO6), U19.18 (B0)
C0: U2.16 (IO4), U6.9 (I9), U10.9 (I9), U11.9 (I9), U12.9 (I9), U13.9 (I9), U14.9 (I9), U15.9 (I9), U16.9 (I9), U17.9 (I9), U22.9 (I9), U23.9 (I9), U24.7 (I7), U25.7 (I7), U26.7 (I7), U27.9 (I9)
C1: U2.17 (I03), U6.8 (I8), U10.8 (I8), U11.8 (I8), U12.8 (I8), U13.8 (I8), U14.8 (I8), U15.8 (I8), U16.8 (I8), U17.8 (I8), U22.8 (I8), U23.8 (I8), U24.6 (I6), U25.6 (I6), U26.6 (I6), U27.8 (I8)
C2: U2.18 (IO2), U6.7 (I7), U10.7 (I7), U11.7 (I7), U12.7 (I7), U13.7 (I7), U14.7 (I7), U15.7 (I7), U16.7 (I7), U17.7 (I7), U22.7 (I7), U23.7 (I7), U24.5 (I5), U25.5 (I5), U26.5 (I5), U27.7 (I7)
C3: U2.19 (IO1), U6.6 (I6), U10.6 (I6), U11.6 (I6), U12.6 (I6), U13.6 (I6), U14.6 (I6), U15.6 (I6), U16.6 (I6), U17.6 (I6), U22.6 (I6), U23.6 (I6), U24.4 (I4), U25.4 (I4), U26.4 (I4), U27.6 (I6)
CARRY: U4.18 (IO2), U13.18 (IO2)
CIN0: U2.15 (IO5), U27.3 (I3)
CLK: U1.18 (IO2), U2.1 (I1/CLK), U3.1 (I1/CLK), U4.1 (I1/CLK), U6.1 (I1/CLK), U10.1 (I1/CLK), U11.1 (I1/CLK), U12.1 (I1/CLK), U13.1 (I1/CLK), U14.1 (I1/CLK), U15.1 (I1/CLK), U16.1 (I1/CLK), U17.1 (I1/CLK), U22.1 (I1/CLK), U23.1 (I1/CLK), U24.1 (I1/CLK), U25.1 (I1/CLK), U26.1 (I1/CLK), U27.1 (I1/CLK)
DBUS0: U8.11 (Q0), U18.2 (A0), U21.11 (B7), U26.3 (I3), U27.13 (IO7)
DBUS1: U8.12 (Q1), U18.3 (A1), U21.13 (B5), U22.13 (IO7), U25.3 (I3)
DBUS2: U8.13 (Q2), U16.13 (IO7), U18.4 (A2), U21.15 (B3), U24.3 (I3)
DBUS3: U8.15 (Q3), U14.13 (IO7), U18.5 (A3), U21.17 (B1)
DBUS4: U8.16 (Q4), U12.13 (IO7), U18.6 (A4), U20.11 (B7)
DBUS5: U8.17 (Q5), U11.13 (IO7), U18.7 (A5), U20.13 (B5)
DBUS6: U9.11 (Q0), U10.13 (IO7), U18.8 (A6), U20.15 (B3)
DBUS7: U4.6 (I6), U6.13 (IO7), U9.12 (Q1), U18.9 (A7), U20.17 (B1)
DBUS8: U3.6 (I6), U4.5 (I5), U9.13 (Q2), U19.11 (B7), U23.13 (IO7)
DBUS9: U3.5 (I5), U4.4 (I4), U9.15 (Q3), U17.13 (IO7), U19.13 (B5)
DBUS10: U3.4 (I4), U4.3 (I3), U9.16 (Q4), U15.13 (IO7), U19.15 (B3)
DBUS11: U3.3 (I3), U4.2 (I2), U9.17 (Q5), U13.13 (IO7), U19.17 (B1)
DEP: U1.6 (I6), U2.3 (I3), U5.8
FIELD0: R22.1, U8.2 (A12), U9.2 (A12), U26.14 (IO6)
FIELD1: R20.1, U8.26 (A13), U9.26 (A13), U25.14 (IO6)
FIELD2: R19.1, U8.1 (A14), U9.1 (A14), U24.14 (IO6)
FLAG: U2.9 (I9), U4.17 (I03)
GND: C1.2, C2.2, C3.2, C4.2, C5.2, C6.2, C7.2, C8.2, C9.2, C10.2, C11.2, C12.2, C13.2, C14.2, C15.2, C16.2, C17.2, C18.2, C19.2, C20.2, C21.2, C22.2, C23.2, C24.2, C25.2, C26.2, C27.2, C28.2, C29.2, C30.2, C31.2, C32.2, D1.1 (K), D2.1 (K), D3.1 (K), D4.1 (K), D5.1 (K), D6.1 (K), D7.1 (K), D8.1 (K), D9.1 (K), D10.1 (K), D11.1 (K), D12.1 (K), D13.1 (K), D14.1 (K), D15.1 (K), D16.1 (K), D17.1 (K), D18.1 (K), D19.1 (K), D20.1 (K), D21.1 (K), D22.1 (K), D23.1 (K), D24.1 (K), D25.1 (K), D26.1 (K), D27.1 (K), D28.1 (K), D29.1 (K), H1.1, H2.1, H3.1, H4.1, J1.2, J2.0 (PAD), J2.8, J2.15, J3.6 (GND), J3.9 (GND), J3.14 (GND), J3.20 (GND), J3.25 (GND), J3.30 (GND), J3.34 (GND), J3.39 (GND), R7.2, R8.2, R9.2, R10.2, U1.7 (I7), U1.8 (I8), U1.9 (I9), U1.10 (GND), U1.11 (I10/~OE), U2.10 (GND), U2.11 (I10/~OE), U3.7 (I7), U3.9 (I9), U3.10 (GND), U3.11 (I10/~OE), U4.7 (I7), U4.10 (GND), U4.11 (I10/~OE), U5.1, U5.7 (GND), U6.10 (GND), U6.11 (I10/~OE), U8.14 (GND), U9.14 (GND), U10.10 (GND), U10.11 (I10/~OE), U11.10 (GND), U11.11 (I10/~OE), U12.10 (GND), U12.11 (I10/~OE), U13.5 (I5), U13.10 (GND), U13.11 (I10/~OE), U14.10 (GND), U14.11 (I10/~OE), U15.10 (GND), U15.11 (I10/~OE), U16.10 (GND), U16.11 (I10/~OE), U17.10 (GND), U17.11 (I10/~OE), U18.10 (GND), U19.1 (A->B), U19.10 (GND), U19.19 (CE), U20.1 (A->B), U20.10 (GND), U20.19 (CE), U21.1 (A->B), U21.10 (GND), U21.19 (CE), U22.10 (GND), U22.11 (I10/~OE), U23.10 (GND), U23.11 (I10/~OE), U24.10 (GND), U24.11 (I10/~OE), U25.10 (GND), U25.11 (I10/~OE), U26.10 (GND), U26.11 (I10/~OE), U27.10 (GND), U27.11 (I10/~OE), X1.4 (GND)
INCP: U1.5 (I5), U2.4 (I4), U5.6
IO: U3.2 (I2), U13.19 (IO1)
unnamed: D1.2 (A), R19.2
unnamed: D2.2 (A), R20.2
unnamed: D3.2 (A), R21.2
unnamed: D4.2 (A), R22.2
unnamed: D5.2 (A), R23.2
unnamed: D6.2 (A), R24.2
unnamed: D7.2 (A), R25.2
unnamed: D8.2 (A), R26.2
unnamed: D9.2 (A), R27.2
unnamed: D10.2 (A), R28.2
unnamed: D11.2 (A), R29.2
unnamed: D12.2 (A), R30.2
unnamed: D13.2 (A), R31.2
unnamed: D14.2 (A), R32.2
unnamed: D15.2 (A), R33.2
unnamed: D16.2 (A), R34.2
unnamed: D17.2 (A), R35.2
unnamed: D18.2 (A), R36.2
unnamed: D19.2 (A), R37.2
unnamed: D20.2 (A), R38.2
unnamed: D21.2 (A), R39.2
unnamed: D22.2 (A), R40.2
unnamed: D23.2 (A), R41.2
unnamed: D24.2 (A), R42.2
unnamed: D25.2 (A), R43.2
unnamed: D26.2 (A), R44.2
unnamed: D27.2 (A), R45.2
unnamed: D28.2 (A), R46.2
unnamed: D29.2 (A), R47.2
unnamed: D30.1 (K), J3.15 (GPIO22)
unnamed: D31.1 (K), J3.12 (GPIO18/PWM0)
unnamed: D32.1 (K), J3.16 (GPIO23)
unnamed: D33.1 (K), J3.11 (GPIO17)
unnamed: D34.1 (K), J3.18 (GPIO24)
unnamed: D35.1 (K), J3.10 (GPIO15/RXD)
unnamed: D36.1 (K), J3.22 (GPIO25)
unnamed: D37.1 (K), J3.8 (GPIO14/TXD)
unnamed: D38.1 (K), J3.7 (GCLK0/GPIO4)
unnamed: D39.1 (K), J3.23 (SCLK0/GPIO11)
unnamed: D40.1 (K), J3.26 (~CE1/GPIO7)
unnamed: D41.1 (K), J3.19 (MOSI0/GPIO10)
unnamed: D42.1 (K), J3.24 (~CE0/GPIO8)
unnamed: D43.1 (K), J3.21 (MISO0/GPIO9)
unnamed: J2.10, U18.17 (B1)
unnamed: J2.12, U18.13 (B5)
unnamed: J2.13, U18.11 (B7)
unnamed: J2.11 (P111), U18.15 (B3)
unnamed: U1.1 (I1/CLK), X1.5 (OUT)
unnamed: U8.20 (~CS), U9.20 (~CS)
unnamed: R7.1, U8.18 (Q6)
unnamed: R8.1, U8.19 (Q7)
unnamed: R9.1, U9.18 (Q6)
unnamed: R10.1, U9.19 (Q7)
unnamed: J2.2, U18.18 (B0)
unnamed: J2.3, U18.16 (B2)
unnamed: J2.4, U18.14 (B4)
unnamed: J2.5, U18.12 (B6)
unnamed: R23.1, U19.2 (A0)
unnamed: R24.1, U19.3 (A1)
unnamed: R25.1, U19.4 (A2)
unnamed: R26.1, U19.5 (A3)
unnamed: R27.1, U19.6 (A4)
unnamed: R28.1, U19.7 (A5)
unnamed: R29.1, U19.8 (A6)
unnamed: R30.1, U19.9 (A7)
unnamed: R31.1, U20.2 (A0)
unnamed: R32.1, U20.3 (A1)
unnamed: R34.1, U20.4 (A2)
unnamed: R35.1, U20.5 (A3)
unnamed: R36.1, U20.6 (A4)
unnamed: R37.1, U20.7 (A5)
unnamed: R38.1, U20.8 (A6)
unnamed: R39.1, U20.9 (A7)
unnamed: R40.1, U21.2 (A0)
unnamed: R41.1, U21.3 (A1)
unnamed: R42.1, U21.4 (A2)
unnamed: R43.1, U21.5 (A3)
unnamed: R44.1, U21.6 (A4)
unnamed: R45.1, U21.7 (A5)
unnamed: R46.1, U21.8 (A6)
unnamed: R47.1, U21.9 (A7)
OP0: U2.8 (I8), U4.15 (IO5), U24.9 (I9), U25.9 (I9), U26.9 (I9)
OP1: U2.7 (I7), U4.14 (IO6)
OP2: U2.6 (I6), U4.13 (IO7)
OP3: U2.5 (I5), U4.12 (IO8)
RST: U1.2 (I2), U2.2 (I2), U5.12
RUN: R33.1, U1.17 (I03)
S0: U2.13 (IO7), U4.9 (I9)
S1: U2.14 (IO6), U4.8 (I8), U24.8 (I8), U25.8 (I8), U26.8 (I8)
START: U1.4 (I4), U5.10
STOP: U1.3 (I3), U5.4
STORE: U2.12 (IO8), U3.8 (I8)
VCC: C4.1, C7.1, C8.1, C9.1, C10.1, C11.1, C12.1, C13.1, C14.1, C15.1, C16.1, C17.1, C18.1, C19.1, C20.1, C21.1, C22.1, C23.1, C24.1, C25.1, C26.1, C27.1, C28.1, C29.1, C30.1, C31.1, C32.1, J2.1, J2.9, R1.2, R2.2, R3.2, R4.2, R5.2, R6.2, R11.2, R12.2, R13.2, R14.2, R15.2, R16.2, R17.2, R18.2, R21.1, R48.2, R49.2, R50.2, U1.20 (VCC), U2.20 (VCC), U3.20 (VCC), U4.20 (VCC), U5.14 (VCC), U6.20 (VCC), U8.28 (VCC), U9.28 (VCC), U10.20 (VCC), U11.20 (VCC), U12.20 (VCC), U13.20 (VCC), U14.20 (VCC), U15.20 (VCC), U16.20 (VCC), U17.20 (VCC), U18.20 (VCC), U19.20 (VCC), U20.20 (VCC), U21.20 (VCC), U22.20 (VCC), U23.20 (VCC), U24.20 (VCC), U25.20 (VCC), U26.20 (VCC), U27.2 (I2), U27.20 (VCC), X1.8 (Vcc)
WRF: U3.19 (IO1), U24.2 (I2), U25.2 (I2), U26.2 (I2)
X0: U4.19 (IO1), U27.16 (IO4)
ZP: U4.16 (IO4), U6.4 (I4), U10.4 (I4), U11.4 (I4), U12.4 (I4), U13.4 (I4), U14.4 (I4), U15.4 (I4), U16.4 (I4), U17.4 (I4), U22.4 (I4), U23.4 (I4), U27.4 (I4)
~DEPSW: C3.1, D32.2 (A), R3.1, U5.9
~INCPSW: C5.1, R4.1, U5.5
~IOCMD: J2.6, U3.16 (IO4)
~IOEN0: U3.17 (I03), U18.19 (CE)
~IORD: J2.14, U3.14 (IO6), U18.1 (A->B)
~IOWR: J2.7, U3.15 (IO5)
~MEMOE: U3.12 (IO8), U8.22 (~OE), U9.22 (~OE)
~MEMWE: U3.13 (IO7), U8.27 (~WE), U9.27 (~WE)
~RSTSW: C1.1, D30.2 (A), R1.1, U5.13
~STARTSW: C6.1, R5.1, U5.11
~STOPSW: C2.1, R2.1, U5.3
~SW0: D34.2 (A), R50.1, U27.12 (IO8)
~SW1: D36.2 (A), R48.1, U22.12 (IO8)
~SW2: D38.2 (A), R17.1, U16.12 (IO8)
~SW3: D40.2 (A), R15.1, U14.12 (IO8)
~SW4: D42.2 (A), R13.1, U12.12 (IO8)
~SW5: D43.2 (A), R12.1, U11.12 (IO8)
~SW6: D41.2 (A), R11.1, U10.12 (IO8)
~SW7: D39.2 (A), R6.1, U6.12 (IO8)
~SW8: D37.2 (A), R49.1, U23.12 (IO8)
~SW9: D35.2 (A), R18.1, U17.12 (IO8)
~SW10: D33.2 (A), R16.1, U15.12 (IO8)
~SW11: D31.2 (A), R14.1, U13.12 (IO8)

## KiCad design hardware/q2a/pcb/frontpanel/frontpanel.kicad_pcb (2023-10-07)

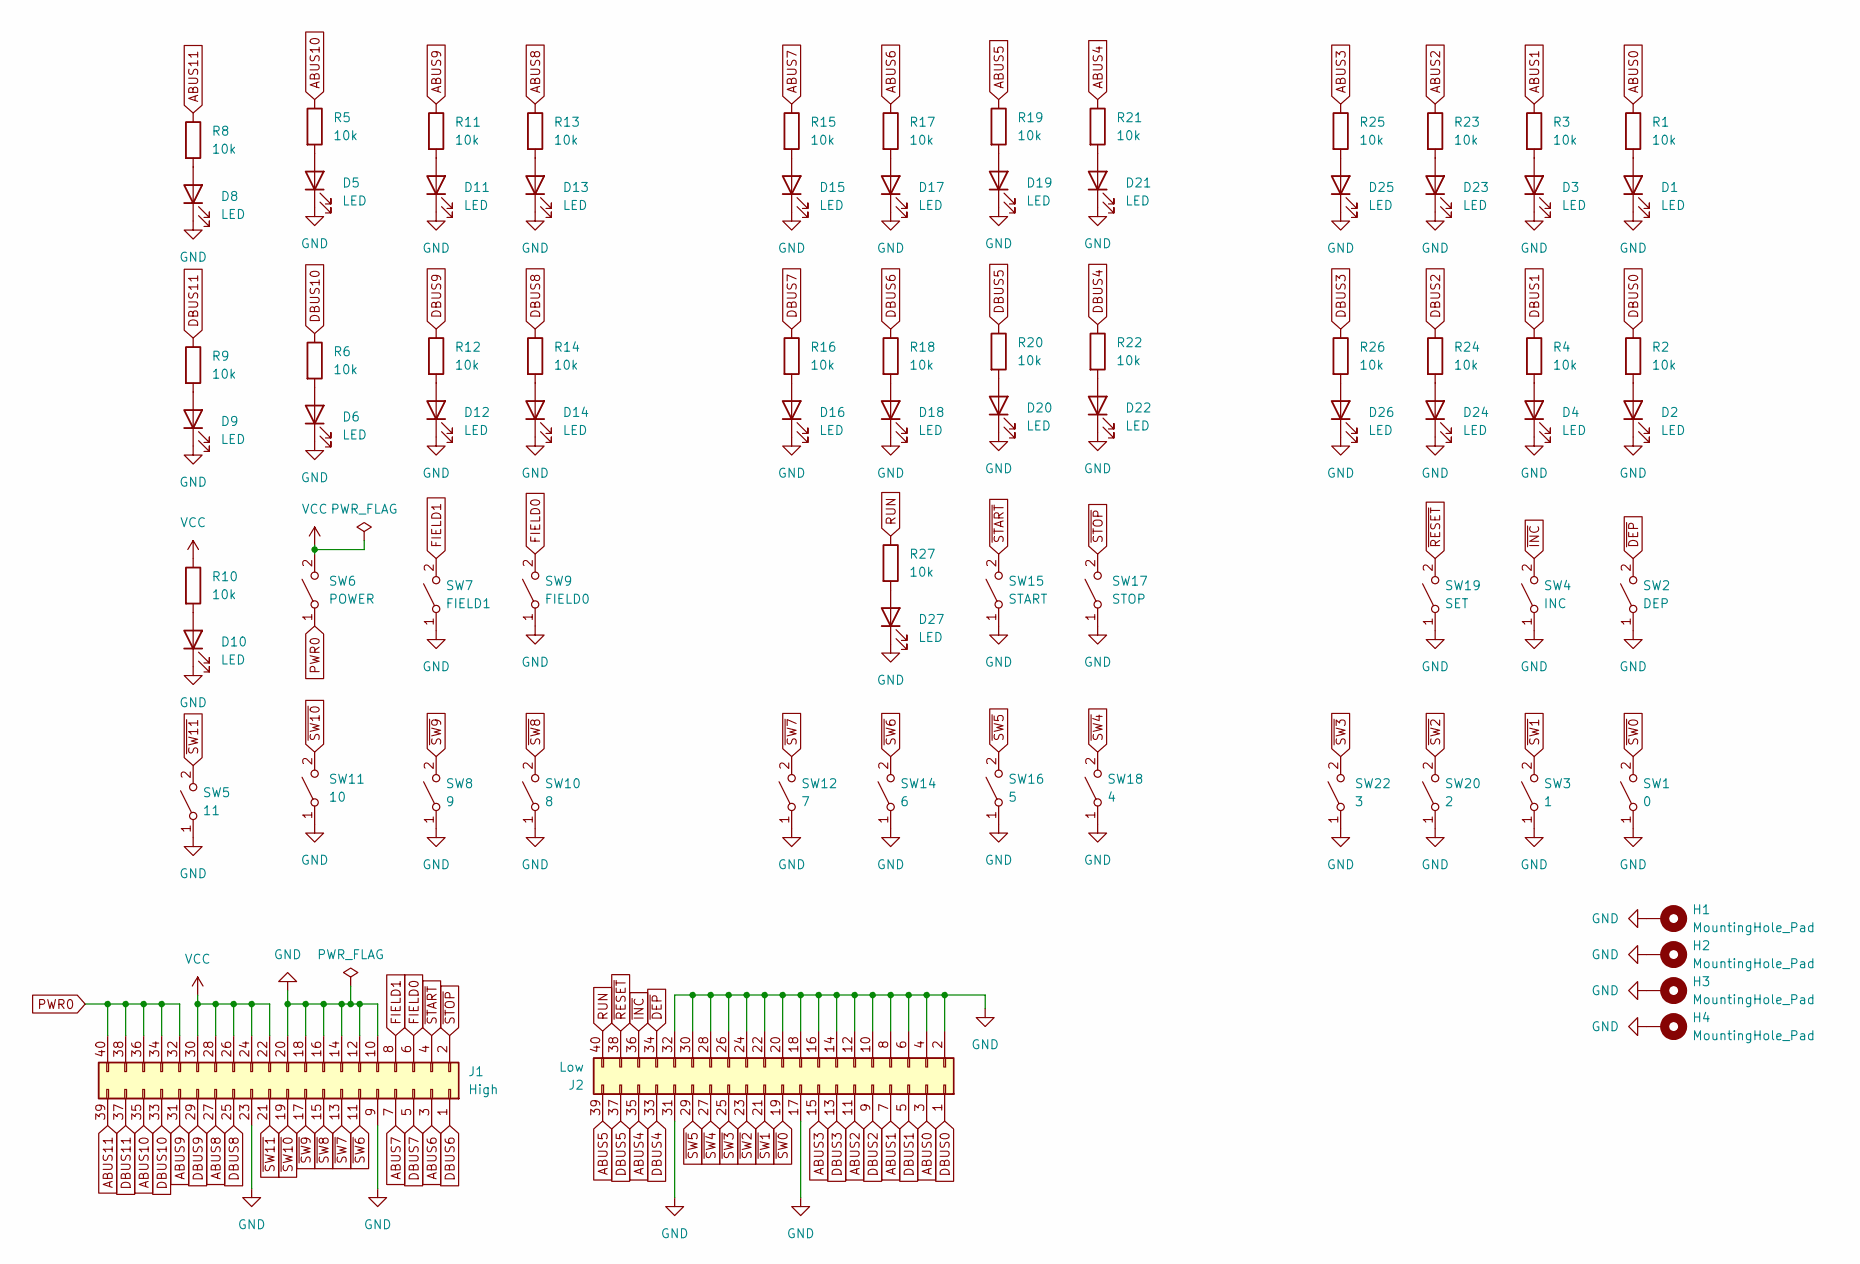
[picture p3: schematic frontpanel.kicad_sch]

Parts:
D1, D2, D3, D4, D5, D6, D8, D9, D10, D11, D12, D13, D14, D15, D16, D17, D18, D19, D20, D21, D22, D23, D24, D25, D26, D27: LED; LED_D3.0mm
H1, H2, H3, H4: MountingHole_Pad; MountingHole_3.2mm_M3_Pad_Via
J1: High; IDC-Header_2x20_P2.54mm_Vertical
J2: Low; IDC-Header_2x20_P2.54mm_Vertical
R1, R2, R3, R4, R5, R6, R8, R9, R10, R11, R12, R13, R14, R15, R16, R17, R18, R19, R20, R21, R22, R23, R24, R25, R26, R27: 10k; R_Axial_DIN0207_L6.3mm_D2.5mm_P10.16mm_Horizontal
SW1: 0; SW_MINI_TOGGLE
SW2: DEP; SW_MINI_TOGGLE
SW3: 1; SW_MINI_TOGGLE
SW4: INC; SW_MINI_TOGGLE
SW5: 11; SW_MINI_TOGGLE
SW6: POWER; SW_MINI_TOGGLE
SW7: FIELD1; SW_MINI_TOGGLE
SW8: 9; SW_MINI_TOGGLE
SW9: FIELD0; SW_MINI_TOGGLE
SW10: 8; SW_MINI_TOGGLE
SW11: 10; SW_MINI_TOGGLE
SW12: 7; SW_MINI_TOGGLE
SW14: 6; SW_MINI_TOGGLE
SW15: START; SW_MINI_TOGGLE
SW16: 5; SW_MINI_TOGGLE
SW17: STOP; SW_MINI_TOGGLE
SW18: 4; SW_MINI_TOGGLE
SW19: SET; SW_MINI_TOGGLE
SW20: 2; SW_MINI_TOGGLE
SW22: 3; SW_MINI_TOGGLE

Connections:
ABUS0: J2.3, R1.1
ABUS1: J2.7, R3.1
ABUS2: J2.11, R23.1
ABUS3: J2.15, R25.1
ABUS4: J2.35, R21.1
ABUS5: J2.39, R19.1
ABUS6: J1.3, R17.1
ABUS7: J1.7, R15.1
ABUS8: J1.27, R13.1
ABUS9: J1.31, R11.1
ABUS10: J1.35, R5.1
ABUS11: J1.39, R8.1
DBUS0: J2.1, R2.1
DBUS1: J2.5, R4.1
DBUS2: J2.9, R24.1
DBUS3: J2.13, R26.1
DBUS4: J2.33, R22.1
DBUS5: J2.37, R20.1
DBUS6: J1.1, R18.1
DBUS7: J1.5, R16.1
DBUS8: J1.25, R14.1
DBUS9: J1.29, R12.1
DBUS10: J1.33, R6.1
DBUS11: J1.37, R9.1
FIELD0: J1.6, SW9.2 (B)
FIELD1: J1.8, SW7.2 (B)
GND: D1.1 (K), D2.1 (K), D3.1 (K), D4.1 (K), D5.1 (K), D6.1 (K), D8.1 (K), D9.1 (K), D10.1 (K), D11.1 (K), D12.1 (K), D13.1 (K), D14.1 (K), D15.1 (K), D16.1 (K), D17.1 (K), D18.1 (K), D19.1 (K), D20.1 (K), D21.1 (K), D22.1 (K), D23.1 (K), D24.1 (K), D25.1 (K), D26.1 (K), D27.1 (K), H1.1, H2.1, H3.1, H4.1, J1.9, J1.10, J1.12, J1.14, J1.16, J1.18, J1.20, J1.23, J2.2, J2.4, J2.6, J2.8, J2.10, J2.12, J2.14, J2.16, J2.17, J2.18, J2.20, J2.22, J2.24, J2.26, J2.28, J2.30, J2.31, J2.32, SW1.1 (A), SW2.1 (A), SW3.1 (A), SW4.1 (A), SW5.1 (A), SW7.1 (A), SW8.1 (A), SW9.1 (A), SW10.1 (A), SW11.1 (A), SW12.1 (A), SW14.1 (A), SW15.1 (A), SW16.1 (A), SW17.1 (A), SW18.1 (A), SW19.1 (A), SW20.1 (A), SW22.1 (A)
unnamed: D1.2 (A), R1.2
unnamed: D2.2 (A), R2.2
unnamed: D3.2 (A), R3.2
unnamed: D4.2 (A), R4.2
unnamed: D5.2 (A), R5.2
unnamed: D6.2 (A), R6.2
unnamed: D8.2 (A), R8.2
unnamed: D9.2 (A), R9.2
unnamed: D10.2 (A), R10.2
unnamed: D11.2 (A), R11.2
unnamed: D12.2 (A), R12.2
unnamed: D13.2 (A), R13.2
unnamed: D14.2 (A), R14.2
unnamed: D15.2 (A), R15.2
unnamed: D16.2 (A), R16.2
unnamed: D17.2 (A), R17.2
unnamed: D18.2 (A), R18.2
unnamed: D19.2 (A), R19.2
unnamed: D20.2 (A), R20.2
unnamed: D21.2 (A), R21.2
unnamed: D22.2 (A), R22.2
unnamed: D23.2 (A), R23.2
unnamed: D24.2 (A), R24.2
unnamed: D25.2 (A), R25.2
unnamed: D26.2 (A), R26.2
unnamed: D27.2 (A), R27.2
PWR0: J1.32, J1.34, J1.36, J1.38, J1.40, SW6.1 (A)
RUN: J2.40, R27.1
VCC: J1.22, J1.24, J1.26, J1.28, J1.30, R10.1, SW6.2 (B)
~DEP: J2.34, SW2.2 (B)
~INC: J2.36, SW4.2 (B)
~RESET: J2.38, SW19.2 (B)
~START: J1.4, SW15.2 (B)
~STOP: J1.2, SW17.2 (B)
~SW0: J2.19, SW1.2 (B)
~SW1: J2.21, SW3.2 (B)
~SW2: J2.23, SW20.2 (B)
~SW3: J2.25, SW22.2 (B)
~SW4: J2.27, SW18.2 (B)
~SW5: J2.29, SW16.2 (B)
~SW6: J1.11, SW14.2 (B)
~SW7: J1.13, SW12.2 (B)
~SW8: J1.15, SW10.2 (B)
~SW9: J1.17, SW8.2 (B)
~SW10: J1.19, SW11.2 (B)
~SW11: J1.21, SW5.2 (B)

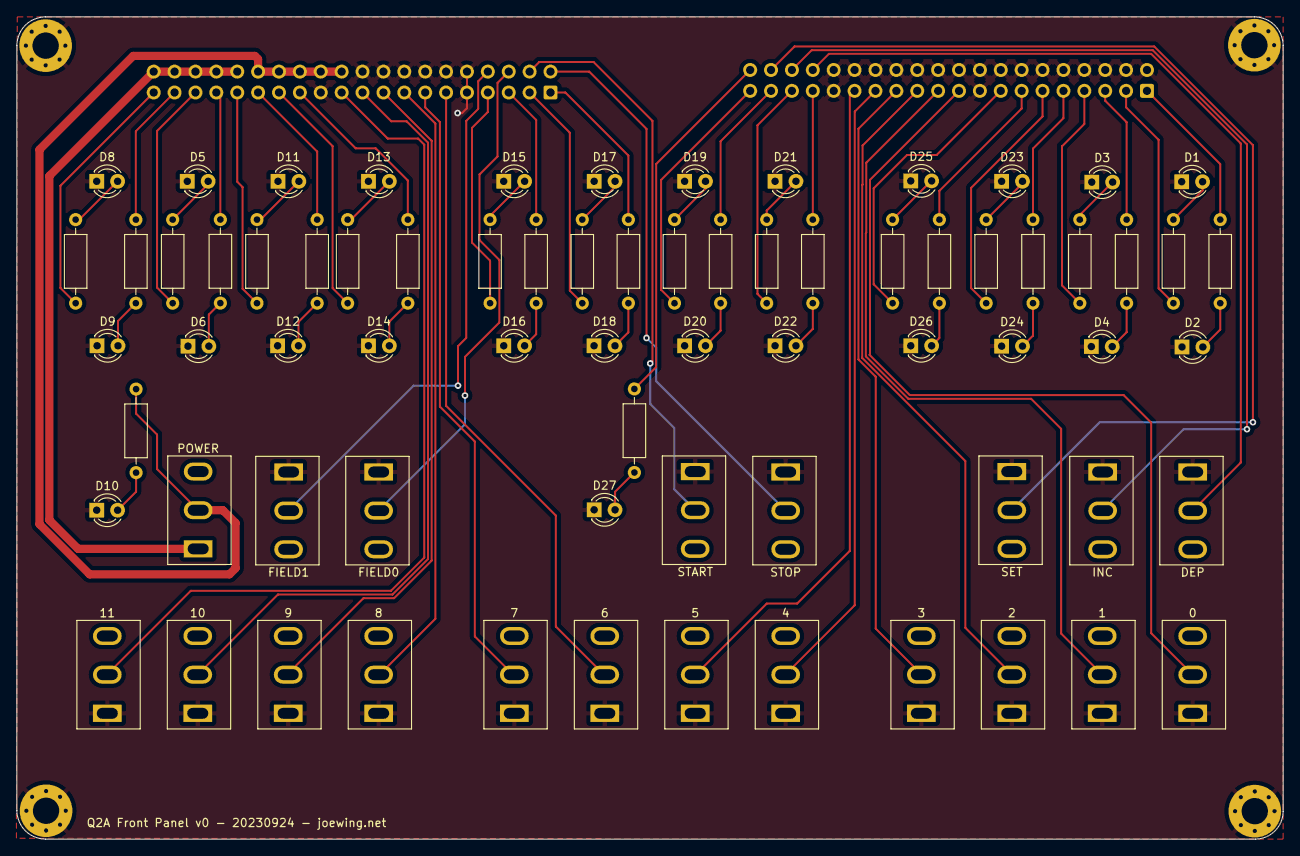
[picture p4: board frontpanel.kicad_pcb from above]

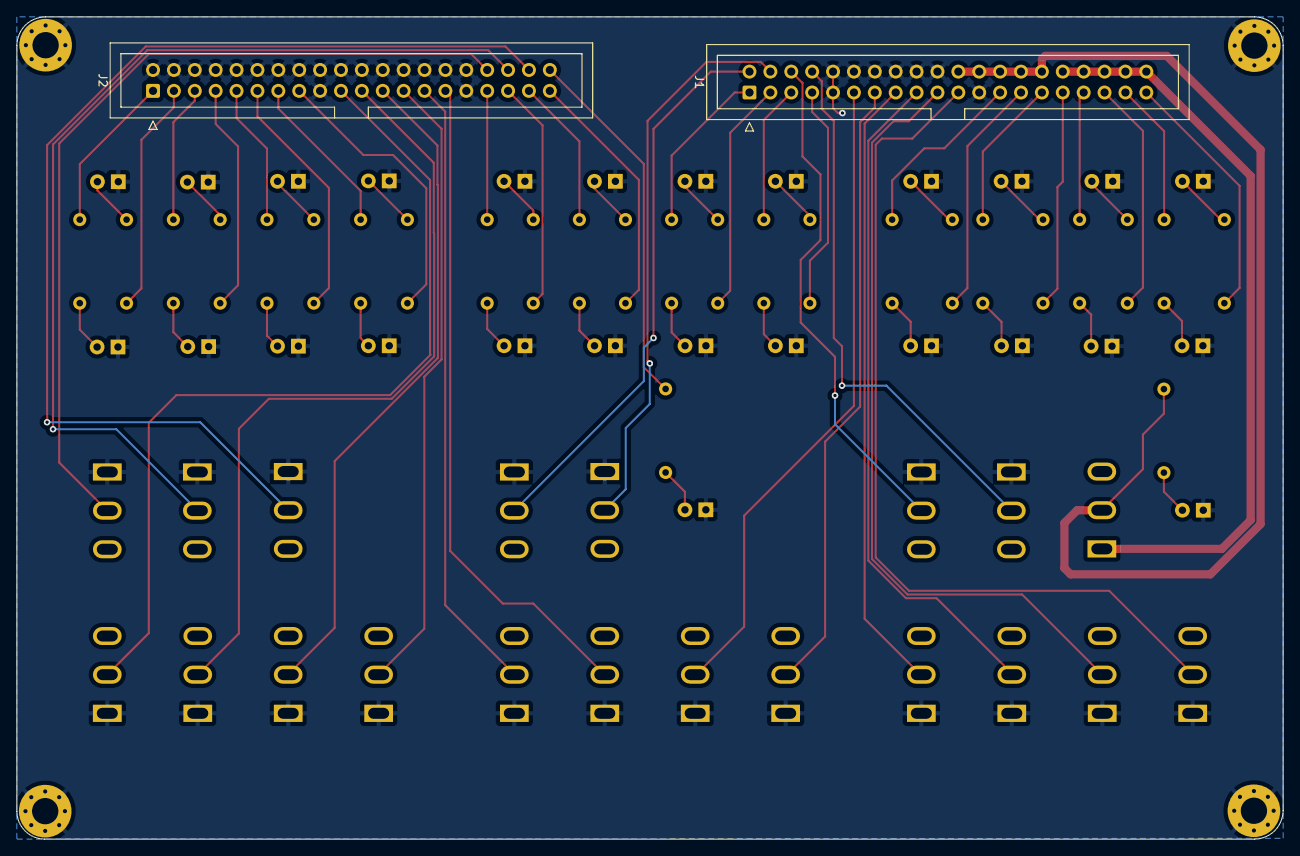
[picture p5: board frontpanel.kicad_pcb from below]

Board: 2 copper layers, 154.0 x 100.0 mm, 78 parts (2 on the bottom side), 73 nets.

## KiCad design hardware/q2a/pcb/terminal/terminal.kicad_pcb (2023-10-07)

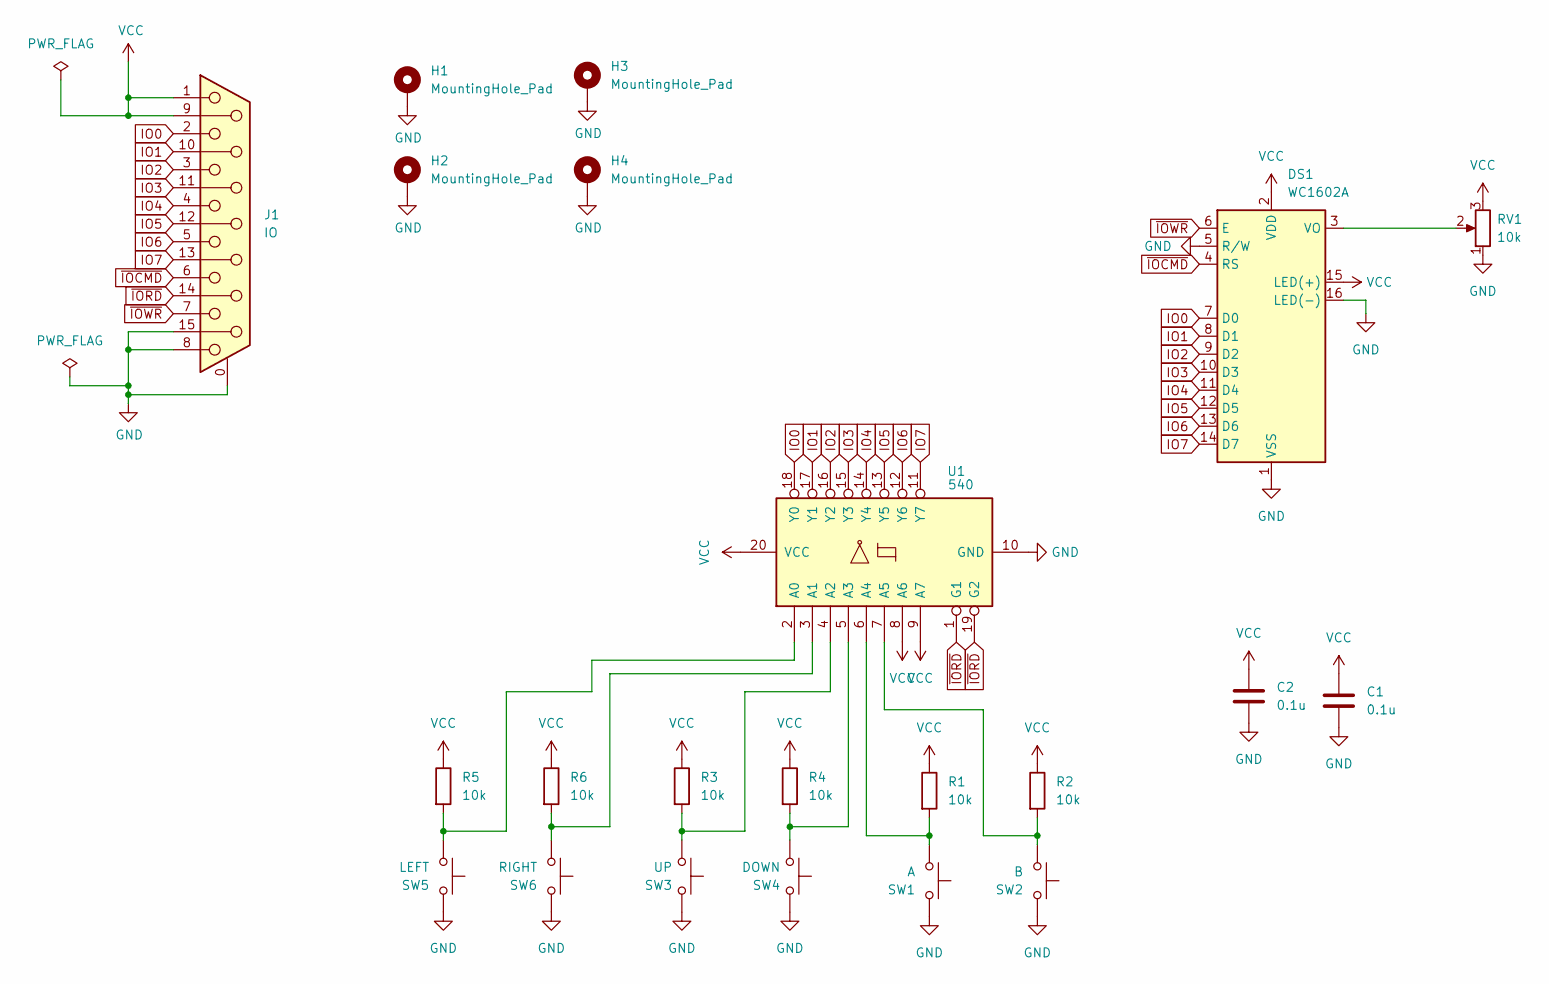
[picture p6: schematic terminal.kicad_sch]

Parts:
C1, C2: 0.1u; C_Disc_D3.4mm_W2.1mm_P2.50mm
DS1: WC1602A
H1, H2, H3, H4: MountingHole_Pad; MountingHole_3.2mm_M3_Pad_Via
J1: IO; DSUB-15_Female_Horizontal_P2.77x2.84mm_EdgePinOffset7.70mm_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
R1, R2, R3, R4, R5, R6: 10k; R_Axial_DIN0207_L6.3mm_D2.5mm_P10.16mm_Horizontal
RV1: 10k; Potentiometer_Bourns_3386P_Vertical
SW1: A; SW_PUSH_6mm
SW2: B; SW_PUSH_6mm
SW3: UP; SW_PUSH_6mm
SW4: DOWN; SW_PUSH_6mm
SW5: LEFT; SW_PUSH_6mm
SW6: RIGHT; SW_PUSH_6mm
U1: 540; DIP-20_W7.62mm_Socket

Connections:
GND: C1.2, C2.2, DS1.1 (VSS), DS1.5 (R/W), DS1.16 (LED(-)), H1.1, H2.1, H3.1, H4.1, J1.0 (PAD), J1.8, J1.15, RV1.1, SW1.2, SW2.2, SW3.2, SW4.2, SW5.2, SW6.2, U1.10 (GND)
IO0: DS1.7 (D0), J1.2, U1.18 (Y0)
IO1: DS1.8 (D1), J1.10, U1.17 (Y1)
IO2: DS1.9 (D2), J1.3, U1.16 (Y2)
IO3: DS1.10 (D3), J1.11 (P111), U1.15 (Y3)
IO4: DS1.11 (D4), J1.4, U1.14 (Y4)
IO5: DS1.12 (D5), J1.12, U1.13 (Y5)
IO6: DS1.13 (D6), J1.5, U1.12 (Y6)
IO7: DS1.14 (D7), J1.13, U1.11 (Y7)
unnamed: DS1.3 (VO), RV1.2
unnamed: R5.2, SW5.1, U1.2 (A0)
unnamed: R6.2, SW6.1, U1.3 (A1)
unnamed: R3.2, SW3.1, U1.4 (A2)
unnamed: R4.2, SW4.1, U1.5 (A3)
unnamed: R1.2, SW1.1, U1.6 (A4)
unnamed: R2.2, SW2.1, U1.7 (A5)
VCC: C1.1, C2.1, DS1.2 (VDD), DS1.15 (LED(+)), J1.1, J1.9, R1.1, R2.1, R3.1, R4.1, R5.1, R6.1, RV1.3, U1.8 (A6), U1.9 (A7), U1.20 (VCC)
~IOCMD: DS1.4 (RS), J1.6
~IORD: J1.14, U1.1 (G1), U1.19 (G2)
~IOWR: DS1.6 (E), J1.7

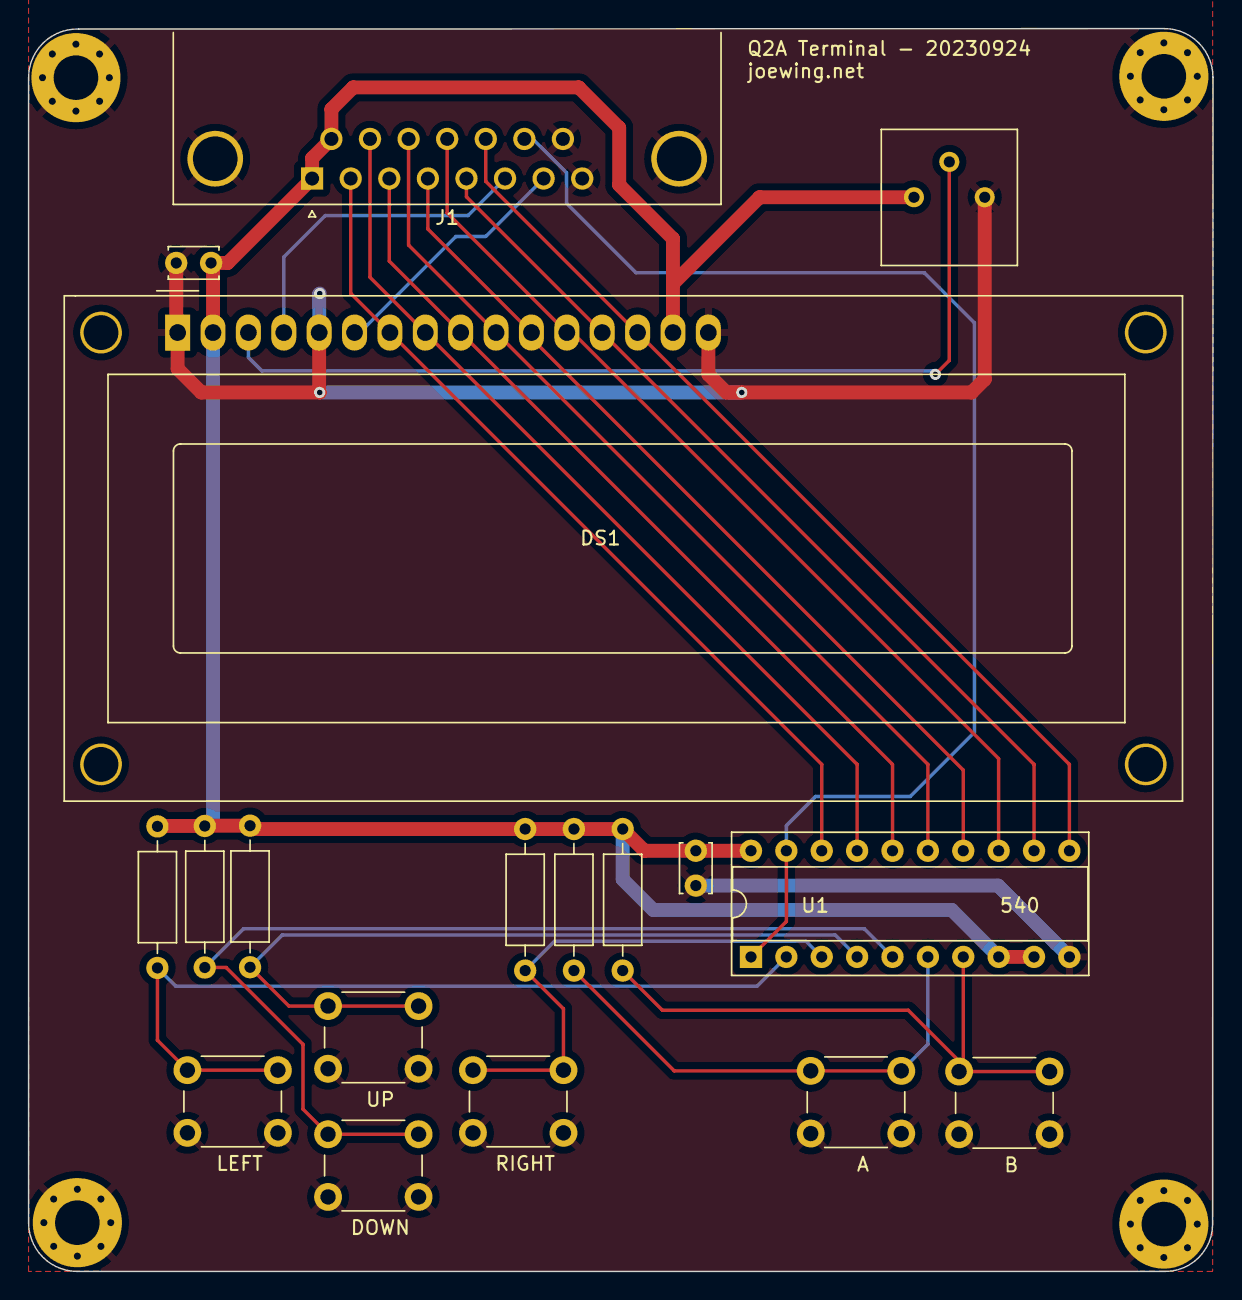
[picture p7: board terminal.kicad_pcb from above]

Board: 2 copper layers, 85.0 x 89.2 mm, 22 parts (0 on the bottom side), 20 nets.

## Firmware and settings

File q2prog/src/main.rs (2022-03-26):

use gpio_cdev::{Chip, LineRequestFlags, MultiLineHandle, LineHandle};
use gpio_cdev::Error;
use std::thread;
use std::time::Duration;
use std::u16;
use std::fs;
use clap::{App, crate_version, crate_authors, crate_name, Arg};
use std::num::ParseIntError;

const DEFAULT_DEVICE_PATH: &str = "/dev/gpiochip0";

// Least significant bits first.
const OUTPUT_PINS: [u32; 12] = [
    24, 25, 4, 7, 8, 9, 10, 11, 14, 15, 17, 18
];
const INPUT_PINS: [u32; 12] = [
    // Input available with 40-pin connector only.
    5, 6, 12, 13, 16, 19, 20, 21, 27, 2, 26, 3
];
const SET_PIN: u32 = 22;
const DEPOSIT_PIN: u32 = 23;

const DELAY_SHORT: Duration = Duration::from_millis(5);
const DELAY_LONG: Duration = Duration::from_millis(25);

pub struct ProgError {
    message: String
}

impl From<std::io::Error> for ProgError {
    fn from(e: std::io::Error) -> ProgError {
        ProgError {
            message: e.to_string()
        }
    }
}

impl From<Error> for ProgError {
    fn from(e: Error) -> ProgError {
        ProgError {
            message: e.to_string()
        }
    }
}

impl From<ParseIntError> for ProgError {
    fn from(e: ParseIntError) -> ProgError {
        ProgError {
            message: e.to_string()
        }
    }
}

pub struct FrontPanel {
    output_lines: MultiLineHandle,
    input_lines: Option<MultiLineHandle>,
    set_line: LineHandle,
    deposit_line: LineHandle
}

impl FrontPanel {
    fn press_button(&self, line: &LineHandle, dur: &Duration) -> Result<(), Error> {
        line.set_value(1)?;
        thread::sleep(DELAY_SHORT);
        line.set_value(0)?;
        thread::sleep(*dur);
        Ok(())
    }

    fn press_set(&self) -> Result<(), Error> {
        self.press_button(&self.set_line, &DELAY_LONG)
    }

    fn press_deposit(&self) -> Result<(), Error> {
        self.press_button(&self.deposit_line, &DELAY_SHORT)
    }

    fn set_value(&self, value: u16) -> Result<(), Error> {
        let mut temp = [0u8; 12];
        for i in 0..12 {
            if (value >> i) & 1 != 0 {
                temp[i] = 1u8;
            }
        }
        self.output_lines.set_values(&temp)
    }

    fn get_value(&self) -> Result<u16, Error> {
        let mut result = 0u16;
        let temp = self.input_lines.as_ref().unwrap().get_values()?;
        for i in 0..12 {
            if temp[i] != 0 {
                result |= 1 << i;
            }
        }
        Ok(result)
    }

    pub fn write_word(&self, addr: u16, word: u16) -> Result<(), Error> {
        eprintln!("write {:03x} = {:03x}", addr, word);
        self.set_value(addr)?;
        self.press_set()?;
        self.set_value(word)?;
        self.press_deposit()
    }

    pub fn read_word(&self, addr: u16) -> Result<u16, Error> {
        self.set_value(addr)?;
        self.press_set()?;
        let word = self.get_value()?;
        eprintln!("read {:03x} = {:03x}", addr, word);
        Ok(word)
    }

    pub fn cleanup(&self) -> Result<(), Error> {
        self.set_value(0u16)?;
        self.press_set()
    }
}

pub fn create_frontpanel(device_path: &str, read_enable: bool) -> Result<FrontPanel, Error> {
    let process_name = "q2prog";
    let mut chip = Chip::new(device_path)?;
    let output_lines = chip.get_lines(&OUTPUT_PINS)?.request(
        LineRequestFlags::OUTPUT | LineRequestFlags::OPEN_DRAIN | LineRequestFlags::ACTIVE_LOW,
        &[0u8; 12],
        process_name
    )?;
    let input_lines = if read_enable {
        Some(
            chip.get_lines(&INPUT_PINS)?.request(
                LineRequestFlags::INPUT | LineRequestFlags::ACTIVE_LOW,
                &[0u8; 12],
                process_name
            )?
        )
    } else {
        None
    };
    let set_line = chip.get_line(SET_PIN)?.request(
        LineRequestFlags::OUTPUT | LineRequestFlags::OPEN_DRAIN | LineRequestFlags::ACTIVE_LOW,
        0u8,
        process_name
    )?;
    let deposit_line = chip.get_line(DEPOSIT_PIN)?.request(
        LineRequestFlags::OUTPUT | LineRequestFlags::OPEN_DRAIN | LineRequestFlags::ACTIVE_LOW,
        0u8,
        process_name
    )?;
    Ok(FrontPanel{ output_lines, input_lines, set_line, deposit_line })
}

fn parse_word(word: &str) -> Result<u16, ProgError> {
    let result = u16::from_str_radix(word, 16)?;
    Ok(result)
}

fn do_write(device_path: &str, filename: &str) -> Result<usize, ProgError> {
    let data = fs::read_to_string(filename)?;
    let panel = create_frontpanel(device_path, false)?;
    let mut count = 0;
    for line in data.split('\n') {
        let parts: Vec<&str> = line.split(':').collect();
        if parts.len() == 2 {
            let addr = parse_word(parts[0])?;
            let word = parse_word(parts[1])?;
            panel.write_word(addr, word)?;
            count += 1;
        } else if line.len() > 0 {
            return Err(ProgError { message: format!("ERROR: invalid line: {}", line) })
        }
    }
    panel.cleanup()?;
    Ok(count)
}

fn do_verify(device_path: &str, filename: &str) -> Result<usize, ProgError> {
    let data = fs::read_to_string(filename)?;
    let panel = create_frontpanel(device_path, true)?;
    let mut count = 0;
    for line in data.split('\n') {
        let parts: Vec<&str> = line.split(':').collect();
        if parts.len() == 2 {
            let addr = parse_word(parts[0])?;
            let word = parse_word(parts[1])?;
            let actual = panel.read_word(addr)?;
            if word != actual {
                panel.cleanup()?;
                return Err(ProgError { message: format!("ERROR: verification failed at {:03X}: expected {:03X}, got {:03X}", addr, word, actual) })
            };
            count += 1;
        } else if line.len() > 0 {
            return Err(ProgError { message: format!("ERROR: invalid line: {}", line) })
        }
    }
    panel.cleanup()?;
    Ok(count)
}

fn do_reset(device_path: &str) -> Result<(), ProgError> {
    let panel = create_frontpanel(device_path, false)?;
    panel.cleanup()?;
    Ok(())
}

fn do_read(device_path: &str, filename: &str, start: u16, end: u16) -> Result<usize, ProgError> {
    let panel = create_frontpanel(device_path, true)?;
    let mut data = String::new();
    let mut count = 0;
    for addr in start..=end {
        let word = panel.read_word(addr)?;
        let line = format!("{:03X}:{:03X}\n", addr, word);
        if filename == "-" {
            println!("{}", line);
        } else {
            data += line.as_str();
        }
        count += 1;
    }
    if filename != "-" {
        fs::write(filename, data)?;
    }
    panel.cleanup()?;
    Ok(count)
}

fn main() {
    let action_key = "ACTION";
    let write_action = "write";
    let read_action= "read";
    let verify_action= "verify";
    let reset_action = "reset";
    let file_key = "FILE";
    let start_key = "START";
    let end_key = "END";
    let device_key = "DEVICE";
    let matches = App::new(crate_name!())
        .version(crate_version!())
        .author(crate_authors!())
        .about("A Raspberry Pi Q2 programmer")
        .max_term_width(80)
        .arg(
            Arg::with_name(action_key)
                .possible_values(&[write_action, read_action, verify_action, reset_action])
                .required(true)
                .help("Action to perform")
        )
        .arg(
            Arg::with_name(file_key)
                .short("-f")
                .long("--file")
                .default_value("out.q2p")
                .help("File name")
        )
        .arg(
            Arg::with_name(start_key)
                .short("-s")
                .long("--start")
                .default_value("000")
                .help("First address to read (hex)")
        )
        .arg(
            Arg::with_name(end_key)
                .short("-e")
                .long("--end")
                .default_value("FFF")
                .help("Last address to read (hex)")
        )
        .arg(
            Arg::with_name(device_key)
                .short("-d")
                .long("--device")
                .default_value(DEFAULT_DEVICE_PATH)
                .help("Device")
        )
        .get_matches();
    let filename = matches.value_of(file_key).unwrap();
    let device_path = matches.value_of(device_key).unwrap();
    if matches.value_of(action_key).unwrap() == write_action {
        match do_write(device_path, filename) {
            Ok(count) => eprintln!("wrote {} words", count),
            Err(e) => eprintln!("write failed: {}", e.message)
        }
    } else if matches.value_of(action_key).unwrap() == verify_action {
        match do_verify(device_path, filename) {
            Ok(count) => eprintln!("verified {} words", count),
            Err(e) => eprintln!("verification failed: {}", e.message)
        }
    } else if matches.value_of(action_key).unwrap() == reset_action {
        match do_reset(device_path) {
            Ok(()) => eprintln!("reset complete"),
            Err(e) => eprintln!("reset failed: {}", e.message)
        }
    } else {
        let start_str = matches.value_of(start_key).unwrap();
        let start = match parse_word(start_str) {
            Ok(v) => v,
            Err(_) => {
                eprintln!("ERROR: invalid start address: {}", start_str);
                return
            }
        };
        let end_str = matches.value_of(end_key).unwrap();
        let end = match parse_word(end_str) {
            Ok(v) => v,
            Err(_) => {
                eprintln!("ERROR: invalid end address: {}", end_str);
                return
            }
        };
        match do_read(device_path, filename, start, end) {
            Ok(count) => eprintln!("read {} words", count),
            Err(e) => eprintln!("read failed: {}", e.message)
        }
    }

}

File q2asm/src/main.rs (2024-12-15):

extern crate clap;
use clap::{App, Arg, crate_version, crate_name, crate_authors};

use std::fs;
use std::env;
use std::error::Error;
use std::str::FromStr;

mod parser;
mod eval;
mod pass1;
mod pass2;

use std::rc::Rc;
use crate::pass2::CompiledStatement;

fn write_str(vec: &mut Vec<u8>, s: &str) -> () {
    vec.extend(s.bytes());
}

fn write_hex(vec: &mut Vec<u8>, word: u16) {

    fn insert(vec: &mut Vec<u8>, x: u16) -> () {
        let hex = b"0123456789ABCDEF";
        vec.push(hex[(x & 15) as usize]);
    }

    insert(vec, word >> 8);
    insert(vec, word >> 4);
    insert(vec, word >> 0);
}

fn write_intel_hex(vec: &mut Vec<u8>, word: u16, addr: i64) {
    let byte_count = 1u8;
    let record_type = 0u8;
    let mut csum = byte_count & 255;
    csum = csum.wrapping_add(record_type & 255);
    csum = csum.wrapping_add((addr >> 8) as u8);
    csum = csum.wrapping_add((addr & 255) as u8);
    csum = csum.wrapping_add((word & 255) as u8);
    csum = (!csum).wrapping_add(1);
    write_str(vec,
              format!(
                  ":{:02X}{:04X}{:02X}{:02X}{:02X}\n",
                  byte_count, addr, record_type, (word & 255), csum
              ).as_ref()
    )
}

trait OutputFormat {

    /** The name of the output format (used as a file extension). */
    fn name(&self) -> &str;

    /** Skip to last_addr to addr (inclusive), generate padding if necessary. */
    fn pad(&self, _vec: &mut Vec<u8>, _last_addr: i64, _addr: i64) -> () {}

    fn write(&self, vec: &mut Vec<u8>, bank: i64, base: u16, st: &CompiledStatement);
    fn write_end(&self, _vec: &mut Vec<u8>) -> () {}
}

struct HexOutputFormat;
impl OutputFormat for HexOutputFormat {
    fn name(&self) -> &str { "hex" }
    fn pad(&self, vec: &mut Vec<u8>, last_addr: i64, addr: i64) {
        for _ in last_addr..addr {
            write_str(vec, "XX\n");
        }
    }
    fn write(&self, vec: &mut Vec<u8>, _bank: i64, _base: u16, st: &CompiledStatement) {
        match st.code {
            Some(word) => {
                write_hex(vec, word);
                write_str(vec, "\n");
            }
            None => ()
        }
    }
}

struct ListOutputFormat;
impl OutputFormat for ListOutputFormat {
    fn name(&self) -> &str { "lst" }
    fn write(&self, vec: &mut Vec<u8>, _bank: i64, _base: u16, st: &CompiledStatement) {
        write_str(vec, format!("{:03X}  ", st.addr).as_ref());
        match st.code {
            Some(word)  => write_hex(vec, word),
            None        => write_str(vec, "    ")
        }
        write_str(vec, &*format!("    {}\n", st.line.as_str()))
    }
}

struct HighRomOutputFormat;
impl OutputFormat for HighRomOutputFormat {
    fn name(&self) -> &str { "high.hex" }
    fn write(&self, vec: &mut Vec<u8>, bank: i64, base: u16, st: &CompiledStatement) {
       match st.code {
           Some(word) => {
               let addr = st.full_addr() - (base as i64);
               write_intel_hex(vec, word >> 6, addr | (bank << 11))
           },
           None => ()
       }
    }
    fn write_end(&self, vec: &mut Vec<u8>) {
        write_str(vec, ":00000001FF\n")
    }
}

struct LowRomOutputFormat;
impl OutputFormat for LowRomOutputFormat {
    fn name(&self) -> &str { "low.hex" }
    fn write(&self, vec: &mut Vec<u8>, bank: i64, base: u16, st: &CompiledStatement) {
        match st.code {
            Some(word) => {
                let addr = st.full_addr() - (base as i64);
                write_intel_hex(vec, word & 0x3F, addr | (bank << 11))
            },
            None => ()
        }
    }
    fn write_end(&self, vec: &mut Vec<u8>) {
        write_str(vec, ":00000001FF\n")
    }
}

struct Q2pOutputFormat;
impl OutputFormat for Q2pOutputFormat {
    fn name(&self) -> &str { "q2p" }
    fn write(&self, vec: &mut Vec<u8>, _bank: i64, _base: u16, st: &CompiledStatement) {
        match st.code {
            Some(word) => {
                write_hex(vec, st.full_addr() as u16);
                write_str(vec, ":");
                write_hex(vec, word);
                write_str(vec, "\n");
            },
            None => ()
        }
    }
}

fn get_output_name(name: &str, suffix: &str) -> String {
    match name.rfind(".") {
        Some(idx) => {
            let mut s = String::from(name);
            s.truncate(idx);
            format!("{}.{}", s, suffix)
        }
        None => format!("{}.{}", name, suffix)
    }
}

struct OutputWriter {
    format: Rc<dyn OutputFormat>,
    output: Vec<u8>
}

fn assemble(
    input_name: &str,
    start_addr: i64,
    bank: i64,
    formats: &Vec<Rc<dyn OutputFormat>>
) -> Result<(), Box<dyn Error>> {
    let mut writers: Vec<OutputWriter> = Vec::new();
    for format in formats {
        writers.push(
            OutputWriter {
                format: format.clone(),
                output: Vec::new()
            }
        );
    }
    let content = fs::read_to_string(input_name)?;
    let statements = parser::parse(input_name, &content)?;
    let (symbols, updated_statements) = pass1::pass1(statements)?;
    let mut result = pass2::pass2(&updated_statements, &symbols)?;
    result.sort_by_key(|s| s.full_addr());
    let mut last_addr: i64 = start_addr;
    let mut base: u16 = 0xFFFF;
    for cs in result {
        if cs.code.is_some() && base == 0xFFFF {
            // Set the base address to be the address of the first instruction.
            base = cs.addr as u16;
        }
        for writer in &mut writers {
            if last_addr != cs.addr {
                writer.format.pad(&mut writer.output, last_addr, cs.addr);
            }
            writer.format.write(&mut writer.output, bank, base, &cs);
        }
        last_addr = cs.addr + if cs.code.is_some() { 1 } else { 0 };
    }
    for mut writer in writers {
        writer.format.write_end(&mut writer.output);
        let output_name = get_output_name(input_name, writer.format.name());
        fs::write(output_name, writer.output)?;
    }
    Ok(())
}
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

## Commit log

2020-03-15 First commit.
    [adder.sch, areg.sch, backplane.kicad_pcb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]
2020-03-22 q2sim and q2asm updates.
    [logic.sch]
2021-04-10 isqrt example
    [backplane.kicad_pcb, backplane.sch, clock.kicad_pcb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]
2021-04-10 New design
    [adder.sch, alu.kicad_pcb, alu.sch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]
2021-04-10 RAM board
    [backplane.kicad_pcb, backplane.sch, case.scad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]
2021-04-10 Add some assembler directives.
    [alu.kicad_pcb, backplane.kicad_pcb, backplane.sch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]
2021-04-10 More fixes
    [backplane.kicad_pcb, backplane.sch, control.kicad_pcb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]
2021-04-10 Start v2.
    More stuff.
    More stuff.
    [alu.sch, areg.sch, bit.sch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]
2021-04-10 v2 PCB.
    [alu.kicad_sch, alu.sch, areg.kicad_sch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]
2021-04-10 Pi programmer.
    [alu.kicad_sch, areg.kicad_sch, bit.kicad_sch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]
2021-04-10 Bit low/high.
    [bit-high.kicad_sch, bit-low.kicad_sch, q2v2.kicad_sch]
2021-04-10 Fewer transistors.
    [alu.kicad_sch, areg.kicad_sch, bit-high.kicad_sch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]
2021-04-10 New reset.
    [alu.kicad_sch, areg.kicad_sch, bit-high.kicad_sch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]
2021-04-10 Skip ALU state for jfc/jmp/sta.
    [alu.kicad_sch, areg.kicad_sch, bit-high.kicad_sch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]
2021-04-10 Fix flag for lea.
    [bit-high.kicad_sch, bit-low.kicad_sch, frontpanel.kicad_sch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]
2021-04-10 Revision 3.
    [alu.kicad_sch, areg.kicad_sch, bit-high.kicad_sch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]
2021-04-10 Fix case.
    [case2.scad]
2021-04-10 Start I2C interface.
    [clock.kicad_sch, decode.kicad_sch, fpbit.kicad_sch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]
2021-04-10 Move stuff.
    [case2.scad, dff.kicad_sch, fpbit.kicad_sch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]
2021-05-10 Start rev4.
    [address.sch, alu.kicad_sch, alu.sch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]
2021-08-11 I2C updates.
    [address.sch, alu.sch, areg.sch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]
2021-09-25 More updates.
    [areg.sch, case2.scad, clock.sch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]
2021-10-09 Timing updates.
    [alu.sch, areg.sch, decoder.sch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]
2021-11-07 Memory extension.
    [address.sch, alu.sch, areg.sch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]
2022-03-12 New oscillator.
    [address.sch, alu.sch, areg.sch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]
2022-03-26 Add q2prog reset action.
    [main.rs]
2022-04-03 Some updates.
    [clock.sch, control.sch, memory.sch]
2022-04-03 I2C fix.
2022-04-16 Better decoupling.
    [address.sch, alu.sch, areg.sch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]
2022-05-07 KiCad 6.
    [address.kicad_sch, address.sch, alu.kicad_sch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]
2022-10-11 PCB fixes/updates.
    [address.kicad_sch, alu.kicad_sch, areg.kicad_sch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]
2022-11-10 Add gerber files.
    [q2-B_Cu.gbl, q2-B_Mask.gbs, q2-B_Paste.gbp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]
2024-12-15 Board updates.
    [address.kicad_sch, alu.kicad_sch, areg.kicad_sch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]
